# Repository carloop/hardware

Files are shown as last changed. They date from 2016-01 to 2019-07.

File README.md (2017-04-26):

<p align="center">
  Carloop Logo
</p>

# [Carloop](https://www.carloop.io)
## OBD-II CAN adapter for the Particle Photon/Electron and RedBear Duo

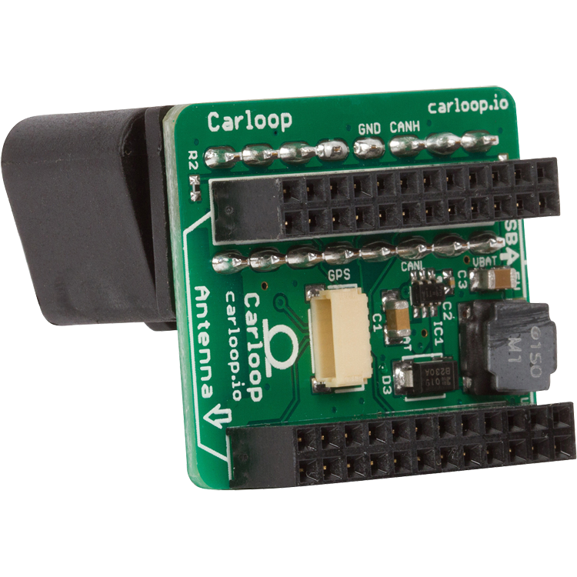
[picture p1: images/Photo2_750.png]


The WiFi-capable Particle Photon or better yet the cellular Particle
Electron can turn your car into a cloud connected device!

Carloop's PCB connects your car's CAN bus network to the Photon, Electron and Duo. It also provides battery power and a GPS to track location.

# Particle Photon Example

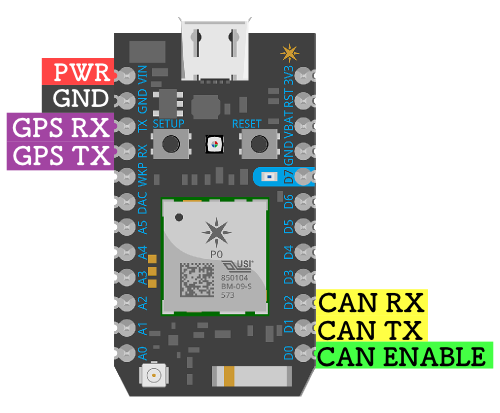
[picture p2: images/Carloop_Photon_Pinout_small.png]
Carloop Photon Pinout


# [Check out the Carloop Store](https://store.carloop.io/)

## Features

* High-speed CAN transceiver [adapted from the OpenXC project](https://github.com/openxc/reference-vi/blob/gh-pages/electrical/design/can.mkd)
* Get power from the OBD-II port using [a robust circuit adapted from the OpenXC project](https://github.com/openxc/reference-vi/blob/gh-pages/electrical/design/power.mkd)
* GPS connector
* Stacked components for a more compact development kit than a
traditional 90-degrees PCB mount OBD-II connector.
* Powered by the Particle platform!

## Images

PCB

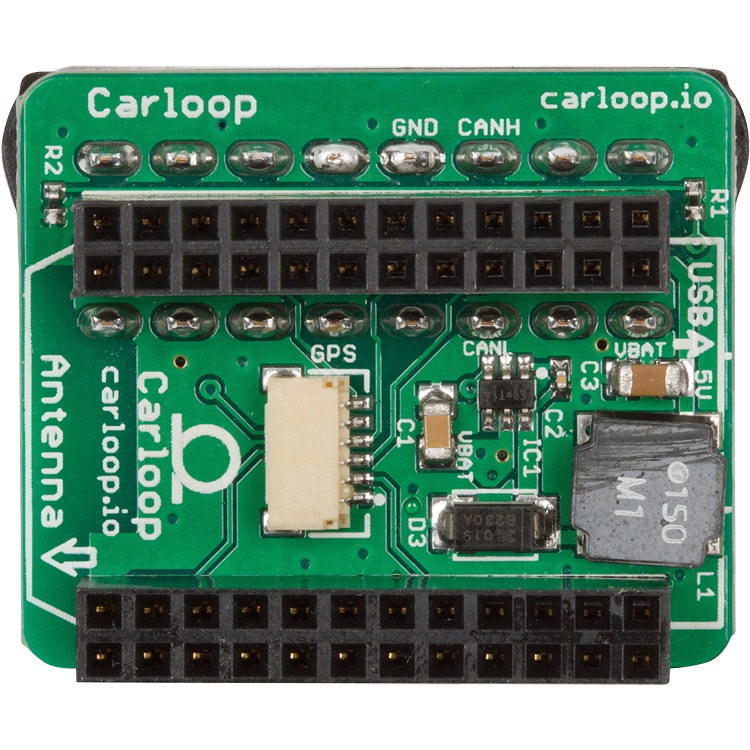
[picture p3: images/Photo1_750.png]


Assembled adapter

* [With Photon](images/detail-photon.jpg)
* [With Electron](images/detail-electron.jpg)
* [Front view](images/front.png)
* [Side view](images/detail-side.jpg)
* [Back view](images/back.png)
* [Angle view](images/angle.png)

## Hardware

There are a few hardware variants: [Carloop](Carloop.v2), [Carloop XL](CarloopXL.v3) and [Carloop Retro](CarloopRetro.v0).

Here are the PCB design files for the Revision 2.3, the one sold on the [Carloop store](https://store.carloop.io)

* [Schematic (PDF)](Carloop.v2/Carloop-v2.3.pdf)
  [(Eagle)](Carloop.v2/Carloop-v2.3.sch)
* [Layout](Carloop.v2/Carloop-v2.3-pcb-combined.pdf)
  [(top)](Carloop.v2/Carloop-v2.3-layout-top.pdf)
  [(bottom)](Carloop.v2/Carloop-v2.3-layout-bottom.pdf)
  [(Eagle)](Carloop.v2/Carloop-v2.3.brd)
* [Bill of materials](Carloop.v2/Carloop-v2.3_BOM.csv)
* [OSH Park order page](https://oshpark.com/shared_projects/ir8I9vT6)

Here are the PCB design files for the extended version that fits a Particle Electron. It is a prototype.

* [Schematic (Eagle)](CarloopXL.v3/Carloop-v3.1.sch)
* [Layout (Eagle)](CarloopXL.v3/Carloop-v3.1.brd)
* [Bill of materials](CarloopXL.v3/Carloop-v3.1_BOM.csv)

Here are the PCB design files for a "retro" variant with a K-Line transceiver contributed by [Alan R](https://github.com/cyclin-al).

* [Schematic (Eagle)](CarloopRetro.v0/CarloopRetro-v0.1.sch)
* [Layout (Eagle)](CarloopRetro.v0/CarloopRetro-v0.1.brd)

## Software

The [Carloop Library](https://github.com/carloop/carloop-library) is available on Particle's Web IDE.  You will need to flash a [Particle Photon](https://store.carloop.io/products/particle-photon), [Particle Electron](https://store.carloop.io/products/particle-electron) or [RedBear Duo](https://store.carloop.io/products/redbear-duo) with an example app which can ben found in Carloop Library.   See 'Getting Started' instructions here: [https://community.carloop.io/t/getting-started-with-carloop/23](https://community.carloop.io/t/getting-started-with-carloop/23)

## License

Copyright 2016 1000 Tools, Inc.

Licensed under the GPL v3

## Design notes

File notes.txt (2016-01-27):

Smaller CAN transceiver:
SN65HVD23x 3.3V 8 pin SOIC
http://www.ti.com/lit/ds/symlink/sn65hvd230.pdf

==> See layout guidelines

TJA1049 8 SOIC with 5V supply and 3.3V IO:
http://www.nxp.com/documents/data_sheet/TJA1049.pdf

Supply: LM2940-N IC REG LDO 5V 1A SOT223
==============> THIS HAS REVERSE BATTERY PROTECTION ELIMINATING 1 COMPONENT!!!!!!
Input cap: CAP CER 0.47UF 50V X7R 0805	C0805C474K5RACTU

Reverse protection diode:

SparkFun uses MBRA140 (1A, 0.56V drop, 40V reverse)

OpenXC uses RS1J (1A, 1.56V drop, 600V reverse)

  ==> Use MBRA140

0.016 width for power supply trace

Make VCC plane around regulator (both sides if possible) and use a bunch
of vias under the case to transfer heat.

MicroSD card => Just connecto to SPI (no external interfacing needed)

Amphenol http://www.digikey.com/product-detail/en/114-00841-68/114-00841-68-1-ND/2187101
Molex http://www.digikey.com/product-detail/en/1040310811/WM6357CT-ND/2804769

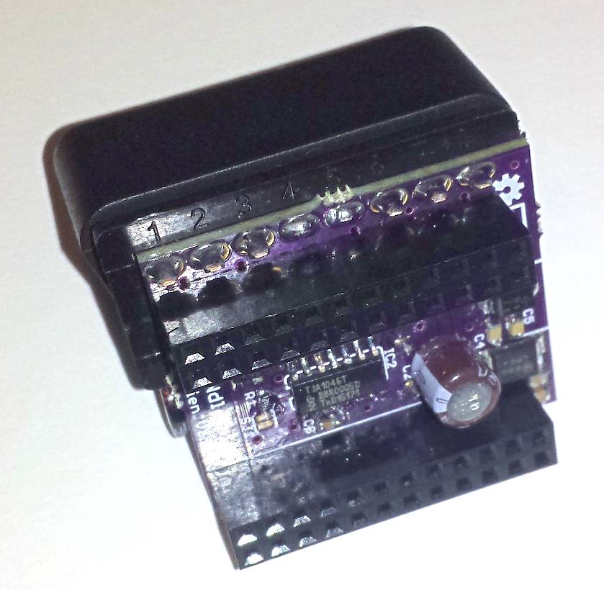
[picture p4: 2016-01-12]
images/detail-angle.jpg

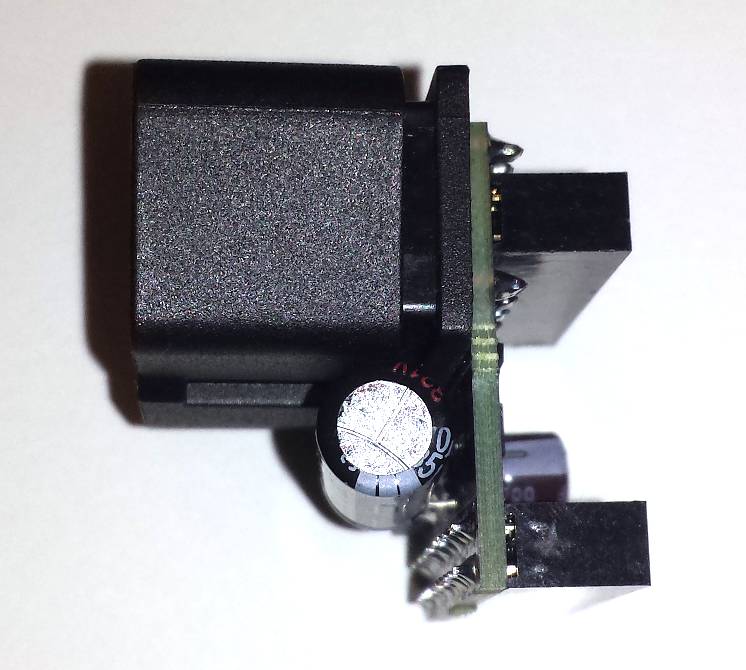
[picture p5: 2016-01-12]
images/detail-side.jpg

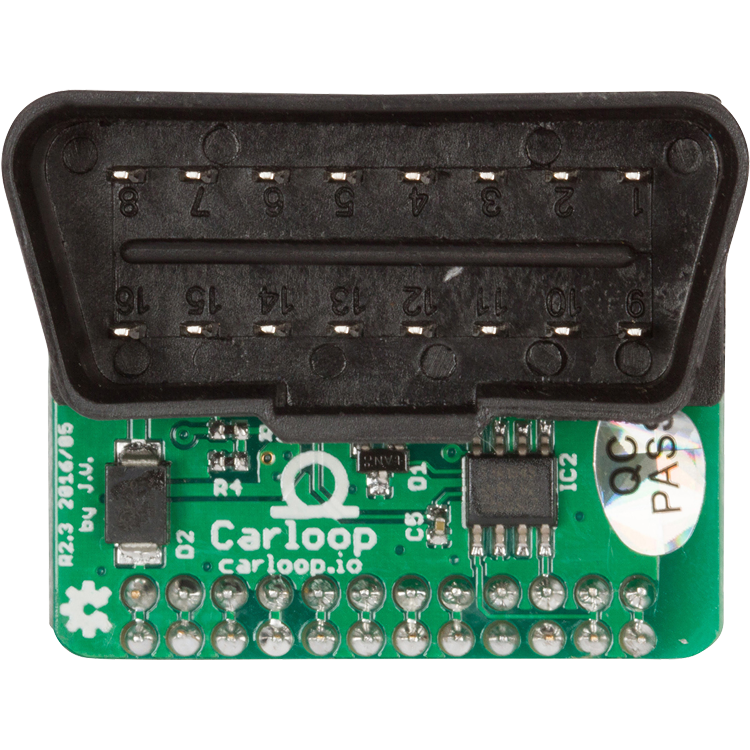
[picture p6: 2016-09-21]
images/back.png

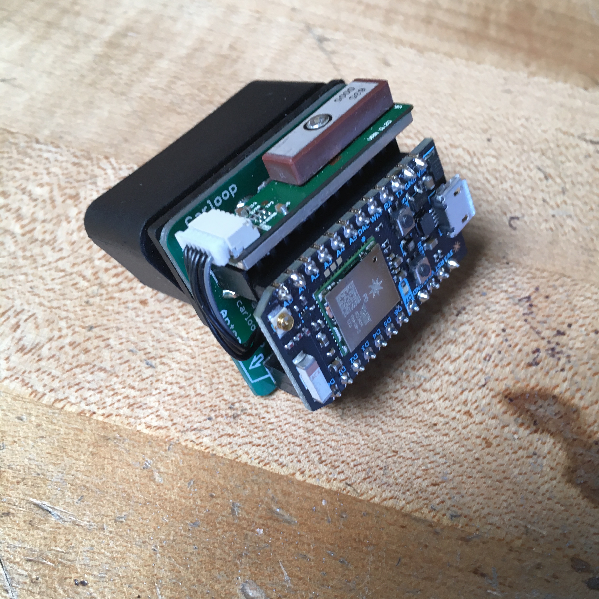
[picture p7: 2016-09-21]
images/detail-photon.jpg

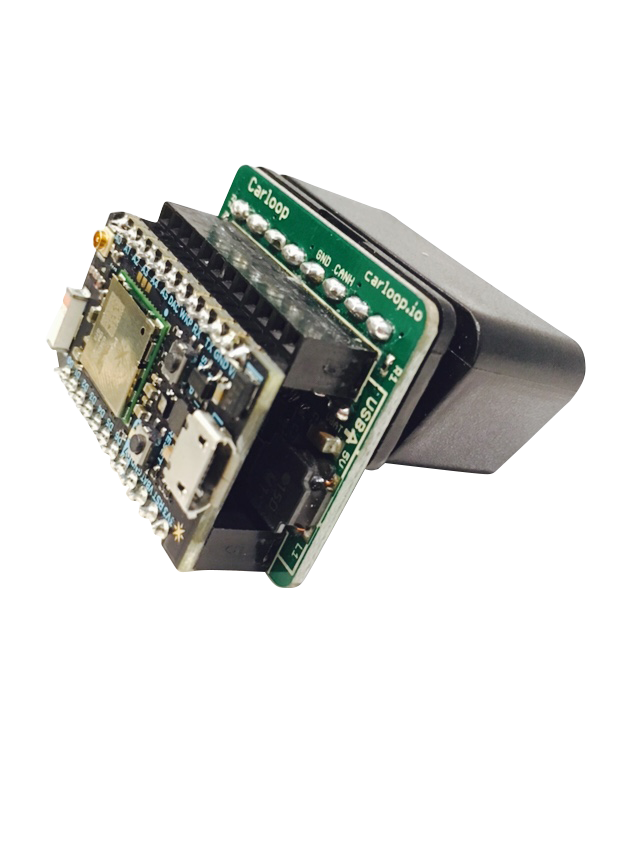
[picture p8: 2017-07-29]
images/Carloop Basic_Transparent_BG.png

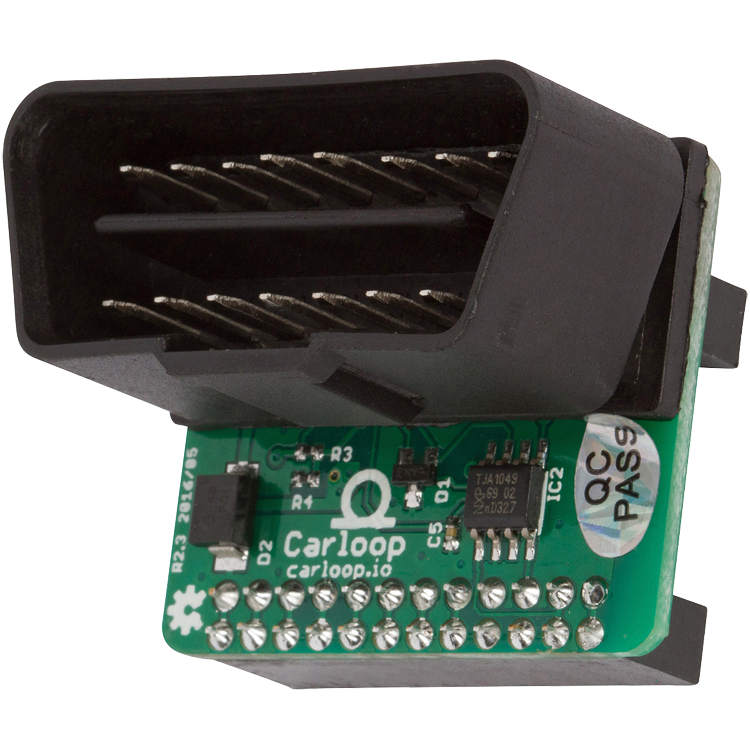
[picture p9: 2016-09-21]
images/angle.png

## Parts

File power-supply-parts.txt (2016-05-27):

Cin: 10uF GRM31CR61E106K
Cout: 22uF GRM31CR61C226M
D1: Schottky B230A-13-F
Cb: 10nF
R1: 91k
R2: 17.4k
L: 15uH NR8040T150M

Reverse protection:
--> 600V 2A silicon ultrafast reverse protection diode
Or Schottky like MBRA140 but for 2A

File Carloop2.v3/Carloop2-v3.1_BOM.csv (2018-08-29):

Qty-1 | Part References | Value | Package | Mfg Part Num | Mfg Name | VID | Vendor Part Num | Description | XREF
1 | J2 |  | SCREWTERMINAL-3.5MM-4 | OSTTE040104 | On Shore Technology Inc. | DK | ED2742-ND | TERMINAL BLOCK 3.5MM 4POS PCB | REF70
3 | C6, C7, C8 | 0.1uF | C0603 | CC0603JRX7R7BB104 | Yageo | DK | 311-1776-1-ND | CAP CER 0.1UF 16V X7R 0603 | REF12
1 | D2 | 1SMB16CAT3G | SMB-DIODE | 1SMB16CAT3G | ON Semiconductor | DK | 1SMB16CAT3GOSCT-ND | TVS DIODE 16VWM 26VC SMB | REF1
1 | R2 | 10k | R0603 | ERA-3AED103V | Panasonic Electronic Components | DK | P123734CT-ND | RES SMD 10K OHM 0.5% 1/10W 0603 | REF92
1 | C2 | 10nF | C0603 | CGA3E2X8R1H103K080AA | TDK Corporation | DK | 445-5892-1-ND | CAP CER 10000PF 50V X8R 0603 | REF88
3 | C1, C11, C12 | 10uF | C1206 | C3216X7R1E106K160AB | TDK Corporation | DK | 445-7705-1-ND | CAP CER 10UF 25V X7R 1206 | REF87
1 | L1 | 15uH | NR8040 | NR8040T150M | Taiyo-Yuden | DK | 587-2643-1-ND | FIXED IND 15UH 2.4A 65 MOHM SMD | REF46
1 | R4 | 17.4k | R0603 | ERJ-3EKF1742V | Panasonic Electronic Components | DK | P17.4KHCT-ND | RES SMD 17.4K OHM 1% 1/10W 0603 | REF93
2 | C4, C5 | 22pF | C0603 | CC0603KRX7R9BB223 | Yageo | DK | 311-1370-1-ND | CAP CER 0.022UF 50V X7R 0603 | REF13
1 | C3 | 22uF | C1206 | CL31X226KAHN3NE | Samsung Electro-Mechanics | DK | 1276-3299-1-ND | CAP CER 22UF 25V X6S 1206 | REF89
1 | Q1 | 40MHz | CRYSTAL-SMD-5X3 | ECS-400-12-30B-AGM-TR | ECS Inc. | DK | XC2600CT-ND | CRYSTAL 40MHZ 12PF SMD | REF84
1 | R1 | 62k | R0603 | ERA-3AEB623V | Panasonic Electronic Components | DK | P62KDBCT-ND | RES SMD 62K OHM 0.1% 1/10W 0603 | REF90
1 | R3 | 91k | R0603 | ERA-3ARB913V | Panasonic Electronic Components | DK | P91KBDCT-ND | RES SMD 91K OHM 0.1% 1/10W 0603 | REF91
1 | IC2 | AZ1117E | SOT223 | AZ1117EH-3.3TRG1 | Diodes Incorporated | DK | AZ1117EH-3.3TRG1DICT-ND | IC REG LINEAR 3.3V 1A SOT223 | REF81
1 | D3 | B230A | DO-214AA | B230A-13-F | Diodes-Incorporated | DK | B230A-FDICT-ND | DIODE SCHOTTKY 30V 2A SMA | REF43
1 | HEADER24 | BOM-PART | * | NPPC122KFMS-RC | Sullins Connector Solutions | DK | S5721-ND | CONN FMALE 24POS DL .1"" GOLD SMD | REF85
1 | HEADER30 | BOM-PART | * | NPTC152KFMS-RC | Sullins Connector Solutions | DK | S5685-ND | CONN FEMALE 30POS DL .1"" TIN SMD | REF86
2 | D4, D5 | MBRA140 | SMA-DIODE | MBRA140T3G | ON Semiconductor | DK | MBRA140T3GOSCT-ND | DIODE SCHOTTKY 40V 1A SMA | REF80
1 | IC4 | MCP2517FD | SOIC-14 | MCP2517FD-H/SL | Microchip Technology | DK | MCP2517FD-H/SL-ND | STAND-ALONE CAN FD CONTROLLER W/ | REF82
1 | J1 | OBDII | OBDII-COMTECH | OBD-II | COMTECH | SF | DEV-09911 | OBD-II connector Straight | REF6
1 | D1 | PESD1CAN | SOT23 | PESD1CAN-215 | NXP Semiconductors | DK | 568-4032-1-ND | TVS DIODE 24VWM 70VC SOT23 | REF2
1 | IC1 | RT8258 | SOT-23-6 | RT8258GJ6 | Richtek | DK | 1028-1044-1-ND | IC REG BUCK ADJ 1.2A TSOT23-6 | REF47
1 | IC3 | TJA1049 | SO8 | TJA1049T-118 | NXP Semiconductors | DK | 568-8682-1-ND | IC CAN TRANSEIVER HS 8SOIC | REF16

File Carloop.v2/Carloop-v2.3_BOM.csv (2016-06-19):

Qty-1 | Part References | Value | Package | Mfg Part Num | Mfg Name | VID | Vendor Part Num | Description | XREF
1 | C5 | 0.1u | C0402 | GRM155R71C104KA88D | Murata | DK | 490-3261-1-ND | 0.10µF ±10% 16V X7R Ceramic Capacitor -55°C ~ 125°C Surface Mount MLCC 0402 | REF48
1 | D2 | 1SMB16CAT3G | SMB-DIODE | 1SMB16CAT3G | ON Semiconductor | DK | 1SMB16CAT3GOSCT-ND | TVS DIODE 16VWM 26VC SMB | REF1
1 | R2 | 10k | R0402 | ERJ-2RKF1002X | Panasonic Electronic Components | DK | P10.0KLCT-ND | RES SMD 10K OHM 1% 1/10W 0402 | REF50
1 | C2 | 10n | C0402 | C0402C103K5RACTU | Kemet | DK | 399-3066-1-ND | 10000pF ±10% 50V X7R Ceramic Capacitor -55°C ~ 125°C Surface Mount MLCC 0402 | REF42
1 | C1 | 10uF | C1206 | GRM31CR61E106KA12L | Murata | DK | 490-3373-1-ND | 10µF ±10% 25V X5R Ceramic Capacitor -55°C ~ 85°C Surface Mount MLCC 1206 | REF40
1 | L1 | 15uH | NR8040 | NR8040T150M | Taiyo-Yuden | DK | 587-2643-1-ND | FIXED IND 15UH 2.4A 65 MOHM SMD | REF46
1 | R4 | 17.4k | R0402 | ERJ-2RKF1742X | Panasonic Electronic Components | DK | P17.4KLCT-ND | RES SMD 17.4K OHM 1% 1/10W 0402 | REF45
1 | C3 | 22u | C1206 | GRM31CR61C226ME15L | Murata | DK | 490-4739-1-ND | 22µF ±20% 16V X5R Ceramic Capacitor -55°C ~ 85°C Surface Mount MLCC 1206 | REF41
1 | R1 | 62k | R0402 | ERJ-2RKF6202X | Panasonic Electronic Components | DK | P62.0KLCT-ND | RES SMD 62K OHM 1% 1/10W 0402 | REF49
1 | R3 | 91k | R0402 | ERJ-2RKF9102X | Panasonic Electronic Components | DK | P91.0KLCT-ND | RES SMD 91K OHM 1% 1/10W 0402 | REF44
1 | D3 | B230A | DO-214AA | B230A-13-F | Diodes-Incorporated | DK | B230A-FDICT-ND | DIODE SCHOTTKY 30V 2A SMA | REF43
2 | HEADER1, HEADER2 | BOM-ENTRY | * | PPPC122LFBN-RC | Sullins Connector Solutions | DK | S7115-ND | Connector Header 24 Position 0.100in (2.54mm) Gold Through Hole | REF8
1 | GPS | JSTHORIZONTAL | JST-6-SMD-HOR-1.0MM | SM06B-SRSS-TB | JST | DK | 455-1806-1-ND | CONN HEADER SH 6POS SIDE 1MM TIN | REF39
1 | J1 | OBDII | OBDII-STRAIGHT | OBD-II | COMTECH | SF | DEV-09911 | OBD-II connector Straight | REF6
1 | D1 | PESD1CAN | SOT23 | PESD1CAN-215 | NXP Semiconductors | DK | 568-4032-1-ND | TVS DIODE 24VWM 70VC SOT23 | REF2
1 | IC1 | RT8258 | SOT-23-6 | RT8258GJ6 | Richtek | DK | 1028-1044-1-ND | IC REG BUCK ADJ 1.2A TSOT23-6 | REF47
1 | IC2 | TJA1049 | SO8 | TJA1049T-118 | NXP Semiconductors | DK | 568-8682-1-ND | IC CAN TRANSEIVER HS 8SOIC | REF16

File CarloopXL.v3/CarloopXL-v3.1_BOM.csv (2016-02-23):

Qty-1 | Part References | Value | Package | Mfg Part Num | Mfg Name | VID | Vendor Part Num | Description | XREF
1 | C1 | .47u | C0805 | C0805C474K5RACTU | Kemet | DK | 399-8100-1-ND | CAP CER 0.47UF 50V X7R 0805 | REF19
2 | C5, C6 | 0.1u | C0805 | 08055C104KAT2A | AVX | DK | 478-1395-1-ND | CAP CER 0.1UF 50V X7R 0805 | REF20
1 | D2 | 1SMB16CAT3G | SMB-DIODE | 1SMB16CAT3G | ON Semiconductor | DK | 1SMB16CAT3GOSCT-ND | TVS DIODE 16VWM 26VC SMB | REF1
1 | C7 | 1u | C0805 | CC0805KKX7R7BB105 | Yageo | DK | 311-1365-1-ND | CAP CER 1UF 16V X7R 0805 | REF26
1 | R2 | 10k | R0805 | ERJ-6ENF1002V | Panasonic Electronic Components | DK | P10.0KCCT-ND | RES SMD 10K OHM 1% 1/8W 0805 | REF38
1 | C2 | 10u | C0805 | GRM21BR6YA106KE43L | Murata | DK | 490-10514-1-ND | CAP CER 10UF 35V X5R 0805 | REF27
1 | C3 | 22u | C0805 | GRM219R61A226MEA0D | Murata | DK | 490-9951-1-ND | CAP CER 22UF 10V X5R 0805 | REF21
1 | R1 | 62k | R0805 | ERJ-6ENF6202V | Panasonic Electronic Components | DK | P62.0KCCT-ND | RES SMD 62K OHM 1% 1/8W 0805 | REF37
1 | D4 | BAT54S | SOT23 | BAT54S-7-F | Diodes Incorporated | DK | BAT54S-FDICT-ND | DIODE ARRAY SCHOTTKY 30V SOT23-3 | REF36
1 | C4 | DNP | C0805 | GRM219R61A226MEA0D | Murata | DK | 490-9951-1-ND | CAP CER 22UF 10V X5R 0805 | REF21
1 | ELECTRON | ELECTRON_WITH_EXTERNAL_HEADERS | ELECTRON_EXTERNAL | PPTC181LFBN-RC | Sullins Connector Solutions | DK | S7016-ND | CONN HEADER FEMALE 18POS.1"" TIN | REF23
1 | GPS | JST | JST-6-SMD-VERT-1.0MM | BM06B-SRSS-TB | JST | DK | 455-1792-1-ND | CONN HEADER SH 6POS TOP 1MM TIN | REF25
1 | IC1 | NCP1117CORRECT | SOT223 | NCP1117LPST50T3G | ON Semiconductor | DK | NCP1117LPST50T3GOSCT-ND | IC REG LDO 5V 1A SOT223 | REF28
1 | J1 | OBDII | OBDII-COMTECH | OBD-II | COMTECH | SF | DEV-09911 | OBD-II connector Straight | REF6
1 | D1 | PESD1CAN | SOT23 | PESD1CAN-215 | NXP Semiconductors | DK | 568-4032-1-ND | TVS DIODE 24VWM 70VC SOT23 | REF2
1 | D3 | RS1J | SMA-DIODE | RS1J-E3/5AT | Vishay | DK | RS1J-E3/5ATGICT-ND | DIODE GEN PURP 600V 1A DO214AC | REF3
1 | IC2 | TJA1049 | SO8 | TJA1049T-118 | NXP Semiconductors | DK | 568-8682-1-ND | IC CAN TRANSEIVER HS 8SOIC | REF16
1 | SDCARD | USD-SOCKETMOLEX-CORRECT | MICRO-SD-MOLEX-CORRECT | 1040310811 | Molex | DK | WM6357CT-ND | CONN MICRO SD CARD PUSH-PULL R/A | REF24

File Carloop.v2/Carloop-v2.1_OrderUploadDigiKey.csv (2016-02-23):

Digi-Key Part No. | Manufacturer Name | Mfr Part No. | Customer Reference | Qty1
1SMB16CAT3GOSCT-ND | ON Semiconductor | 1SMB16CAT3G | D3 | 12
478-1395-1-ND | AVX | 08055C104KAT2A | C5 | 12
399-8100-1-ND | Kemet | C0805C474K5RACTU | C1 | 12
P10.0KCCT-ND | Panasonic Electronic Components | ERJ-6ENF1002V | R2 | 12
P62.0KCCT-ND | Panasonic Electronic Components | ERJ-6ENF6202V | R1 | 12
490-9951-1-ND | Murata | GRM219R61A226MEA0D | C3 | 12
LM2940IMP-5.0/NOPBCT-ND | Texas Instruments | LM2940IMP-5.0/NOPB | IC1 | 12
568-4032-1-ND | NXP Semiconductors | PESD1CAN-215 | D1 | 12
S7115-ND | Sullins Connector Solutions | PPPC122LFBN-RC | CORE | 12
455-1806-1-ND | JST | SM06B-SRSS-TB | GPS | 12
568-8682-1-ND | NXP Semiconductors | TJA1049T-118 | IC2 | 12

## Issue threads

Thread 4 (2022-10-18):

Carloop as extension to Flipper Zero

amra, 2022-10-18:
[Flipper Zero](https://flipperzero.one/) is a hacking device released this year. It supports 3rd-party modules.

Adapt Carloop hardware, so it can be adapted as Flipper Zero module.

### Example: WiFi module
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

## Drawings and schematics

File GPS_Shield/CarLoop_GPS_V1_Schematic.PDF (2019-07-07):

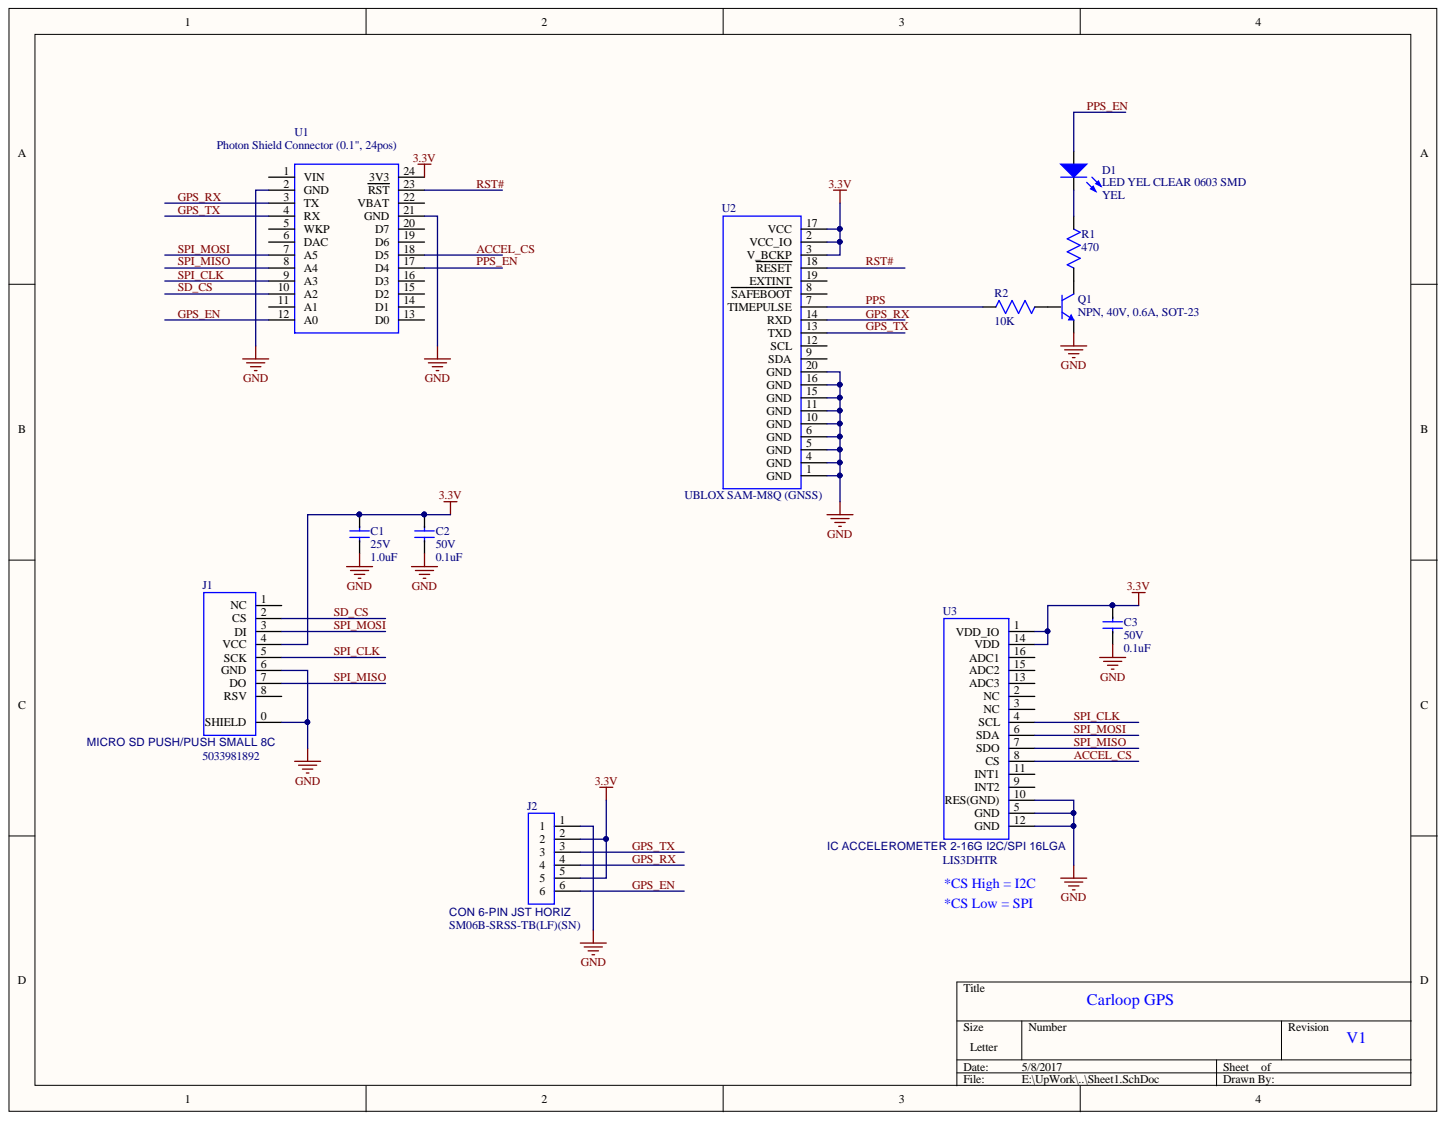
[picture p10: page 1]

MICRO SD PUSH/PUSH S

PIN JST HORIZ
6B-SRSS-TB(LF)(SN

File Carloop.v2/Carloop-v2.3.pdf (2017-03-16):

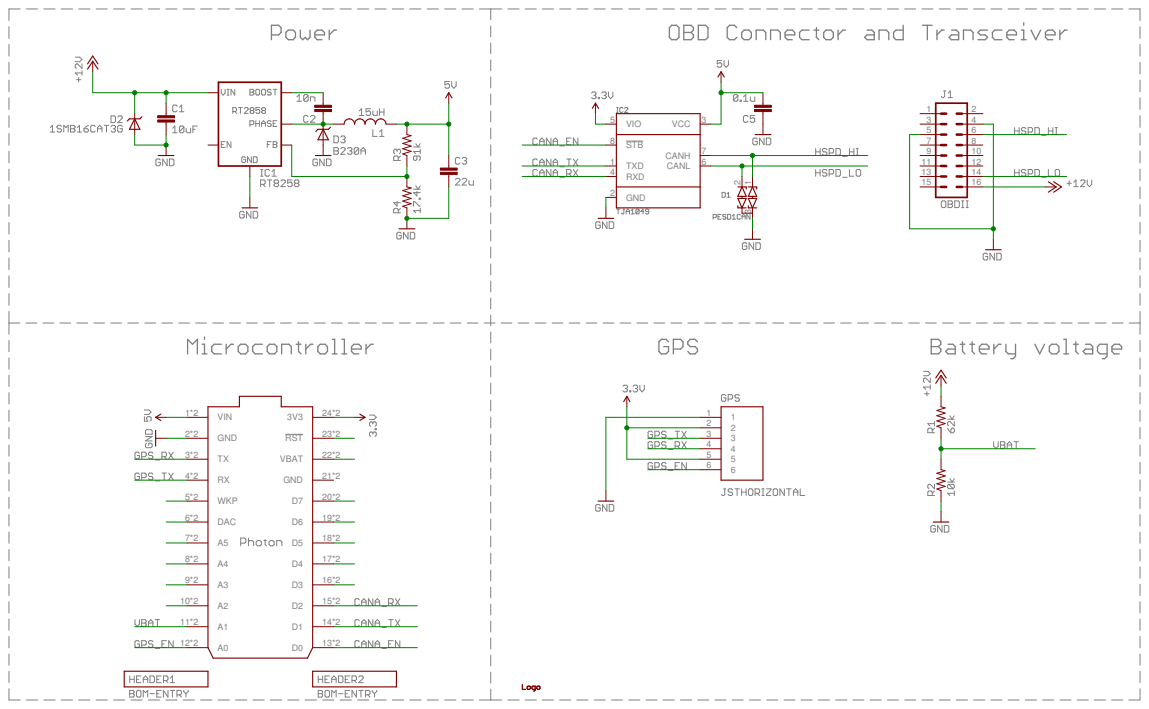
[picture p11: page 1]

21 3 1 2 3 4 5 6 7 8 9 10 11 12 13 14 15 16 VIN 1*2 GND 2*2 TX 3*2 RX 4*2 WKP 5*2 DAC 6*2 A5 7*2 A4 8*2 A3 9*2 A2 10*2 A1 11*2 A0 12*2 3V3 24*2 RST 23*2 VBAT 22*2 GND 21*2 D7 20*2 D6 19*2 D5 18*2 D4 17*2 D3 16*2 D2 15*2 D1 14*2 D0 13*2 STB 8 CANH 7 CANL 6 GND 2 RXD 4 TXD 1 VCC 3 VIO 5 1 1 2 2 3 3 4 4 5 5 6 6

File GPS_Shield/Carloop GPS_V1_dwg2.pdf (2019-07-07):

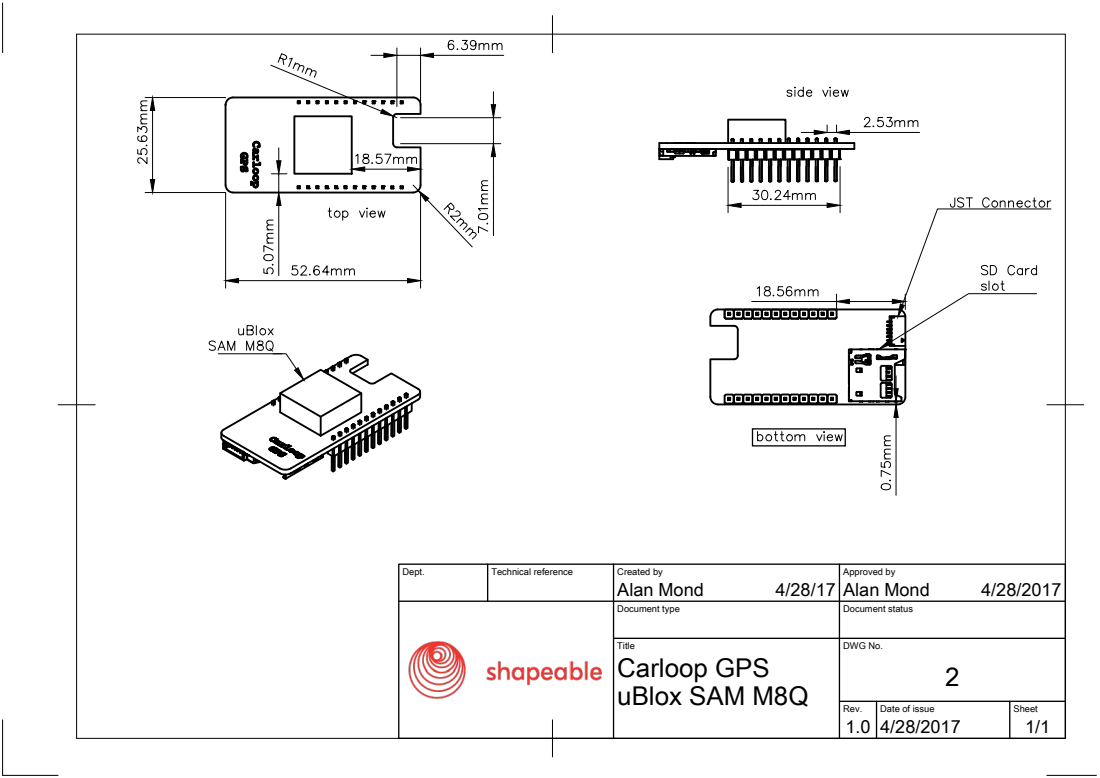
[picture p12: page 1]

Dept. | Technical reference | Created by Alan Mond 4/28/17 | Approved by Alan Mond 4/28/2017

Document type | Document status

Title Carloop GPS uBlox SAM M8Q | DWG No. 2

Rev. 1.0 | Date of issue 4/28/2017 | Sheet 1/1

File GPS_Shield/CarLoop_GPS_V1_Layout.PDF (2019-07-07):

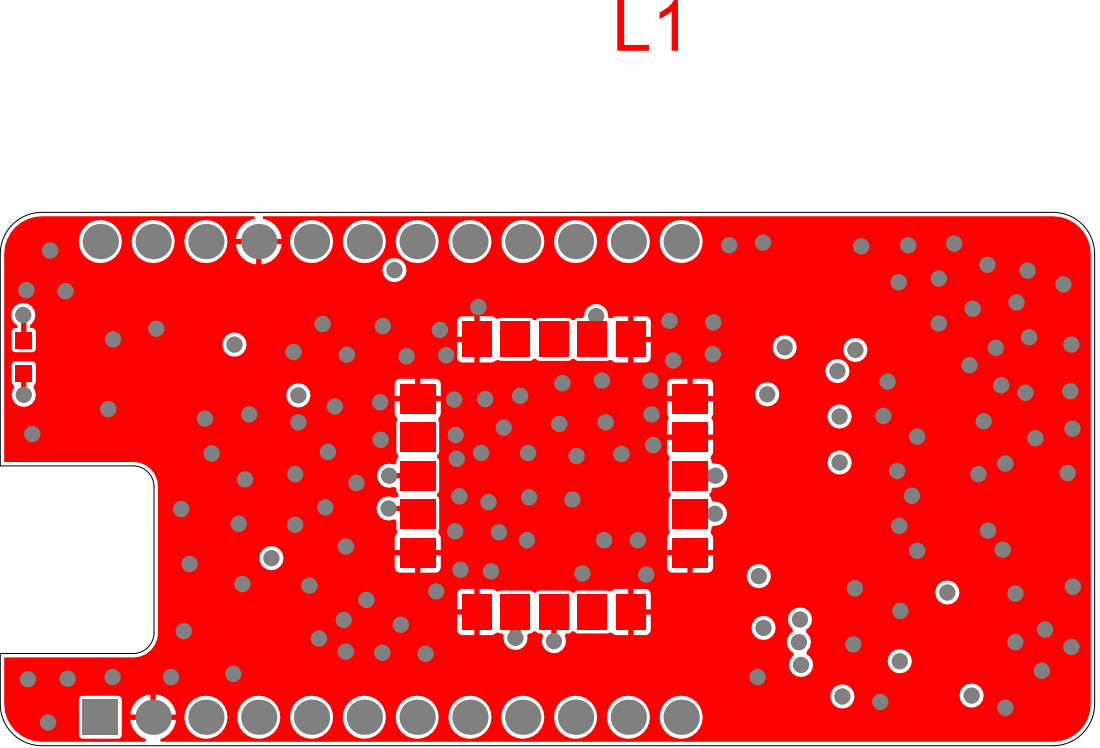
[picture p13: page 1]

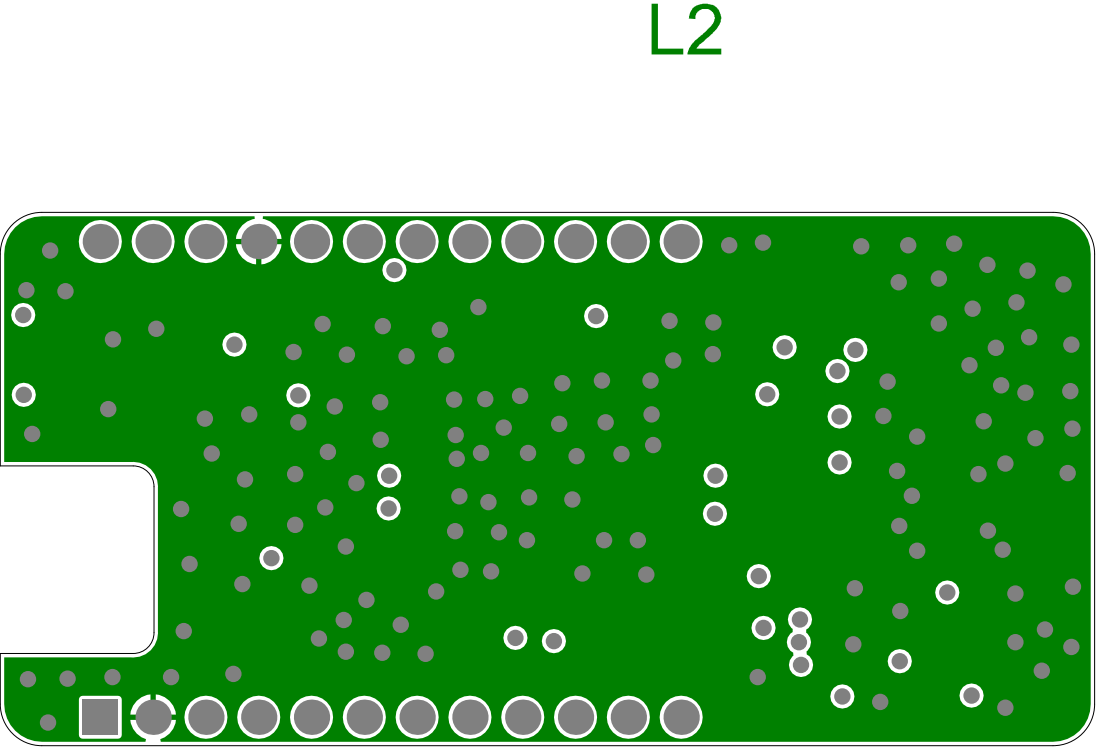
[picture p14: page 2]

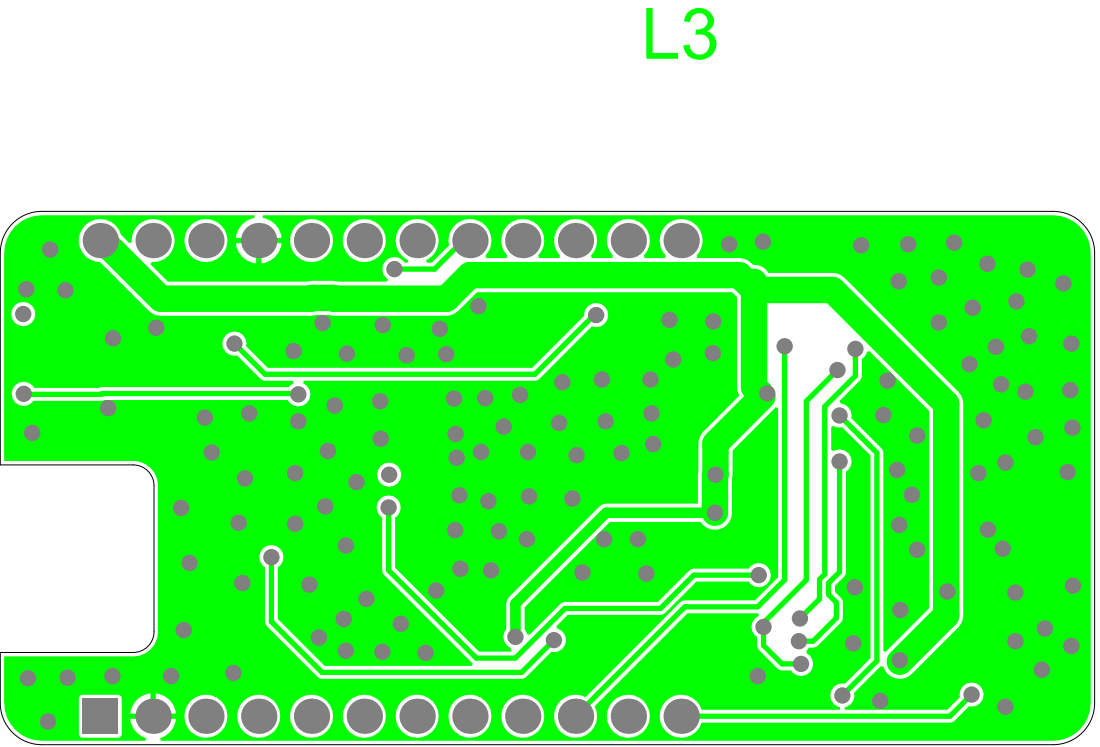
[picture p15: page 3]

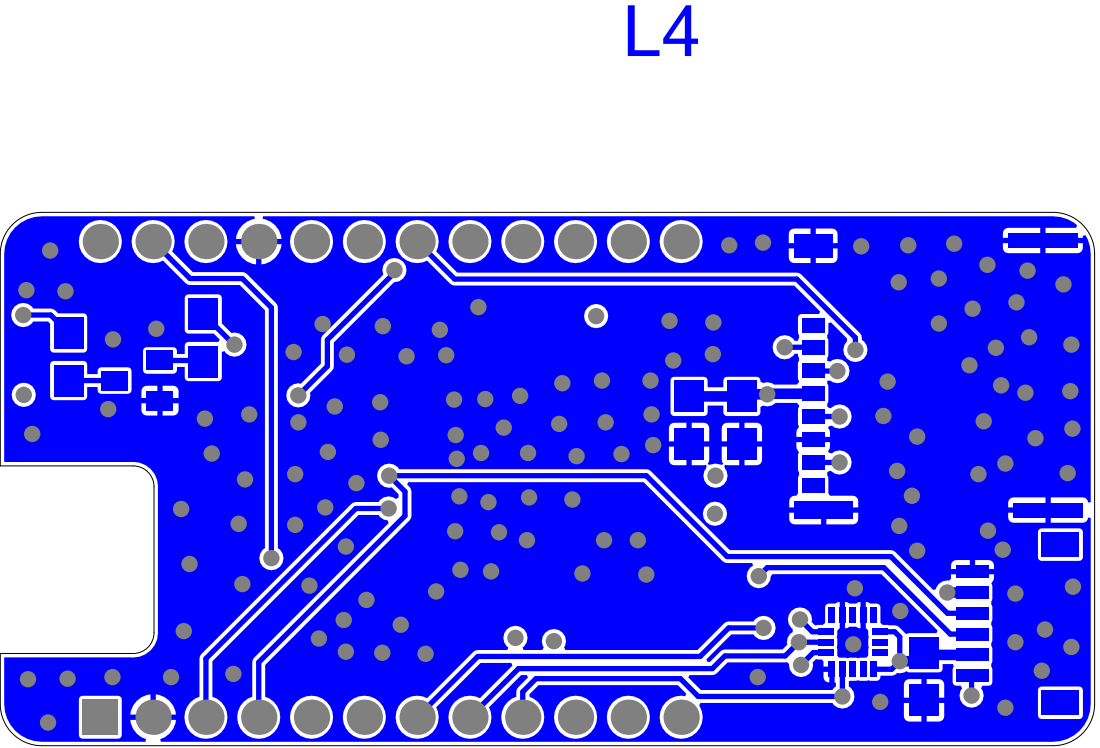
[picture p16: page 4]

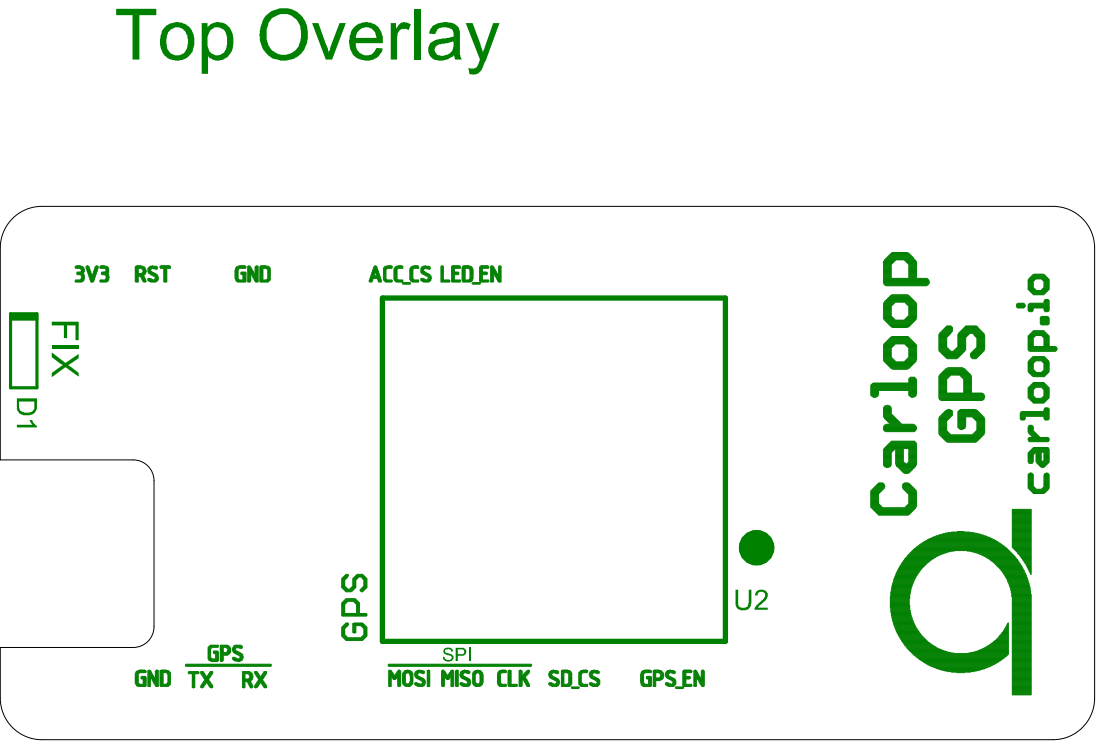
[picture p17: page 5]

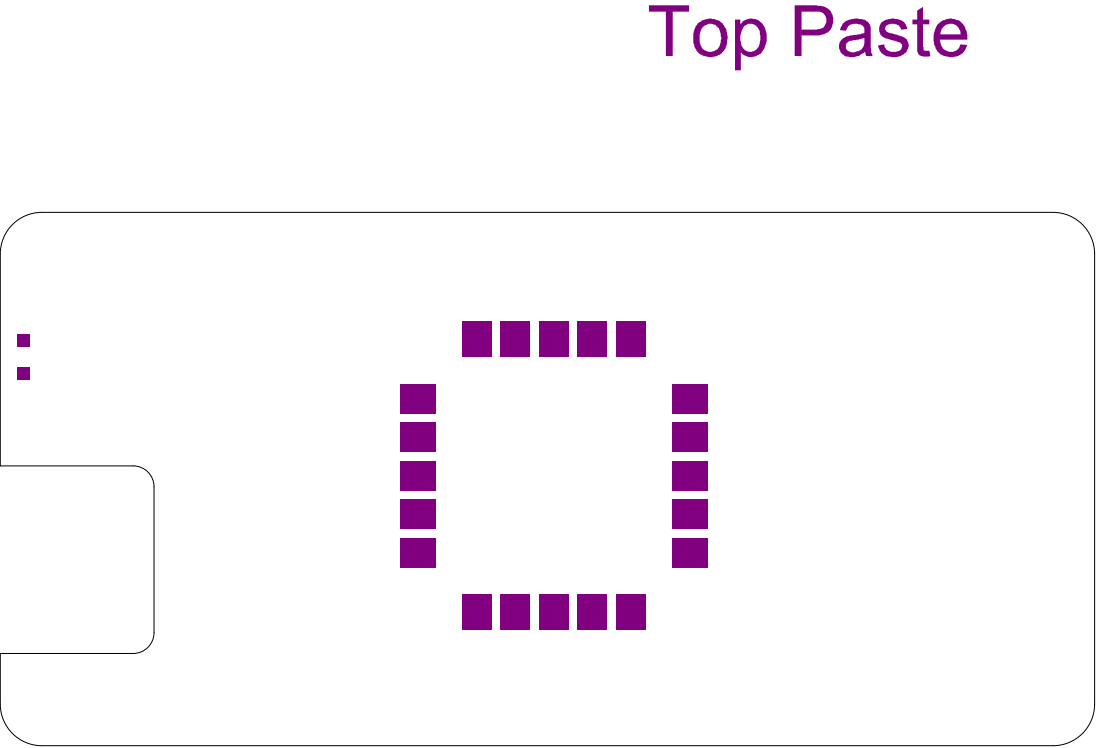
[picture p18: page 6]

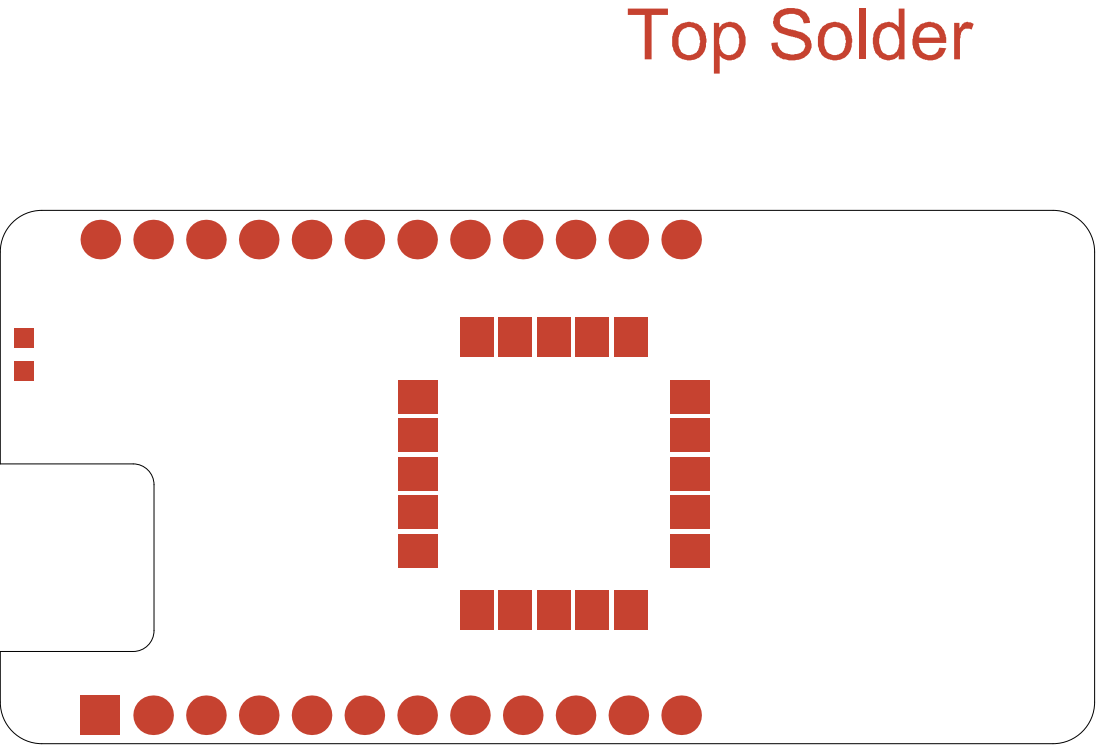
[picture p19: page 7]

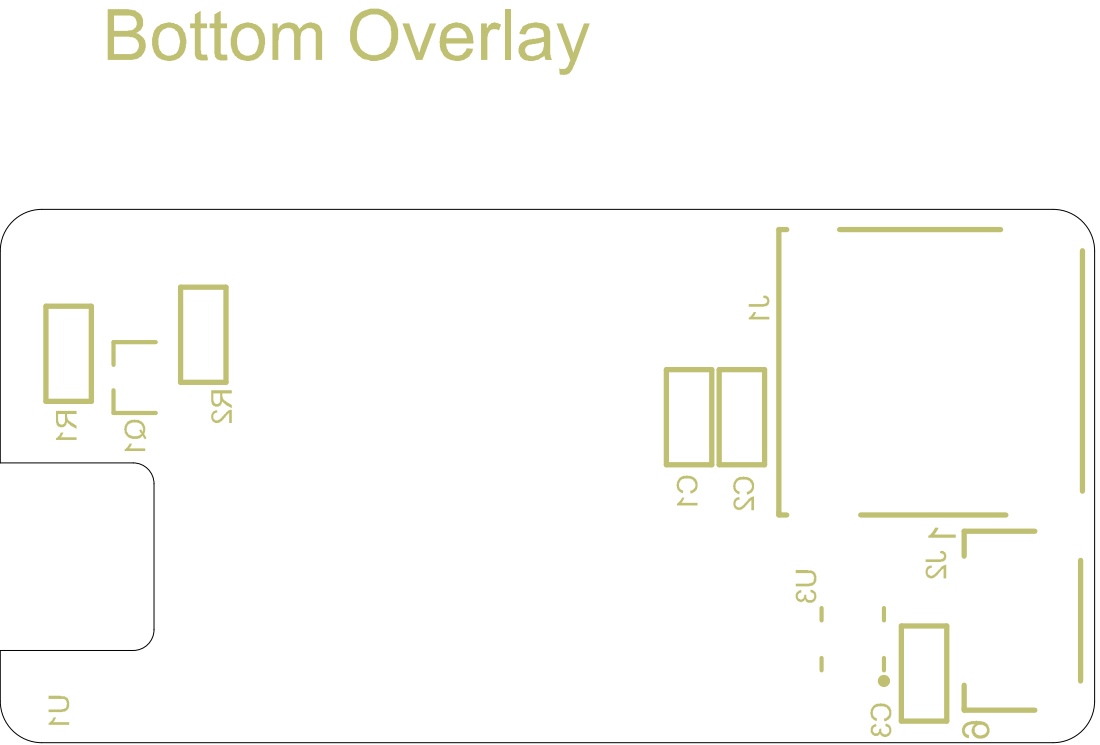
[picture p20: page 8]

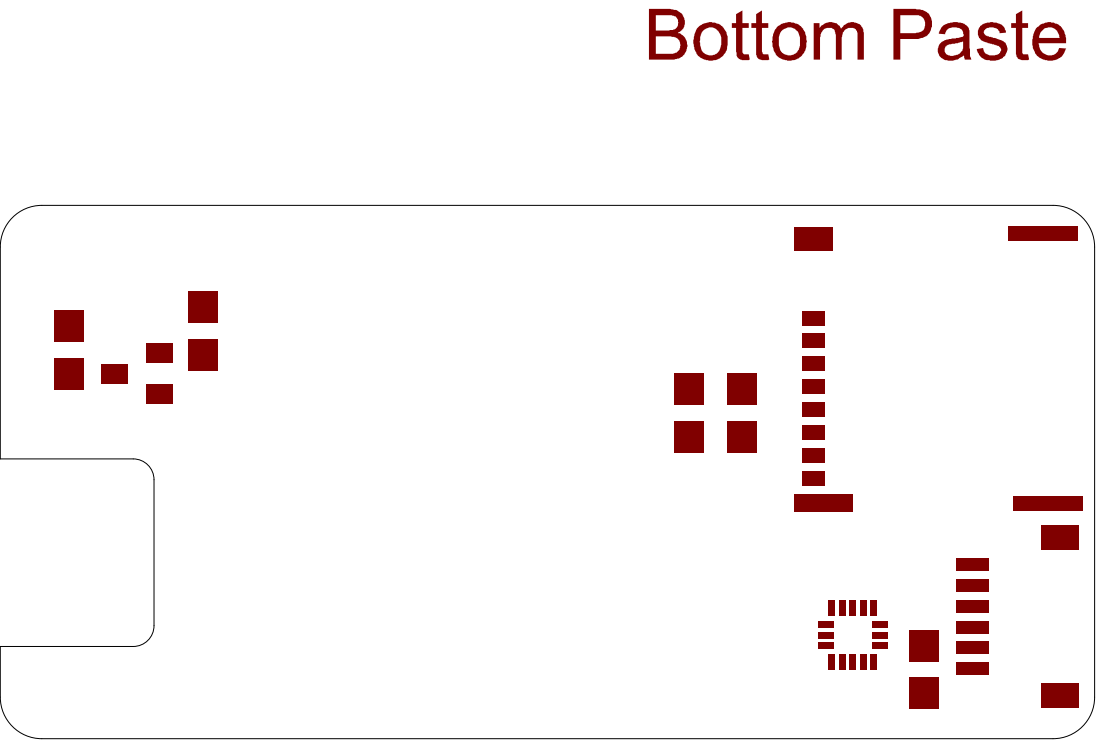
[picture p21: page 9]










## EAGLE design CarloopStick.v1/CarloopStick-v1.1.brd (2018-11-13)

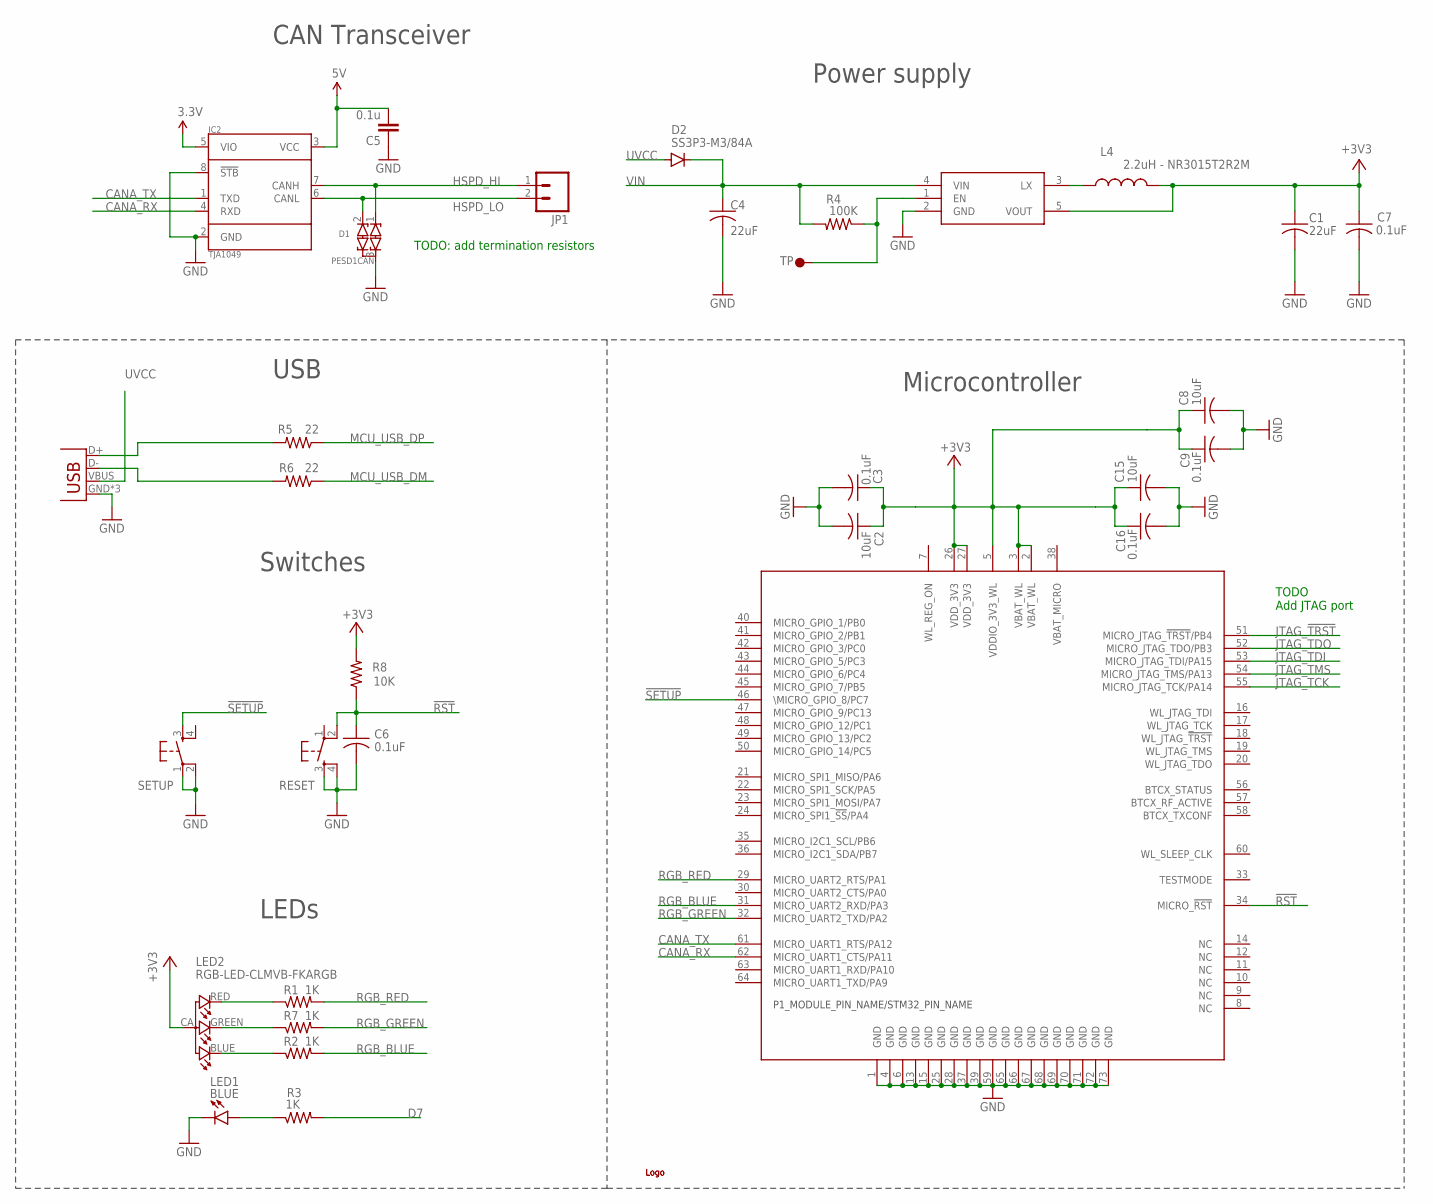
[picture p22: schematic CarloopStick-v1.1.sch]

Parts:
C1, C4: 22uF; C0603_B
C2, C8, C15: 10uF; C0603_B
C3, C6, C7, C9, C16: 0.1uF; C0402_B
C5: 0.1u; C0402; PARTNO GRM155R71C104KA88D
D1: PESD1CAN; SOT23; PARTNO PESD1CAN-215
D2: SS3P3-M3/84A; DIODE-DO-220AA(SMP)
IC2: TJA1049; SO8; PARTNO TJA1049T-118
JP1: M02PTH; 1X02
L4: 2.2uH - NR3015T2R2M; INDUCTOR-NR3015
LED2: RGB-LED-CLMVB-FKARGB; PLCC4-2MM-RGB
LED_USR: BLUE; LED-0603-NO-SS
R1, R2, R3, R7: 1K; R0402_B
R4: 100K; R0402_B
R5, R6: 22; R0402_B
R8: 10K; R0402_B
RESET: KMR211GLFS; TACTILE_SWITCH_SMD
SETUP: KMR211GLFS; TACTILE_SWITCH_SMD
U$1, U$5: LOGOSMALL; CARLOOP-2
U$4: P1; WM-N-BM-14
U$11: R8008-33; SOT23-5
U$12: TP3; TP60_BOT
X1: USB-MICROB; USB-MICROB-SLOT-HOLE

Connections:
3.3V: IC2.5 (VIO)
5V: C5.2, IC2.3 (VCC)
!RST: C6.1, R8.1, RESET.2, U$4.34 (MICRO_!RST!)
!SETUP: SETUP.3, U$4.46 (\MICRO_GPIO_8/PC7)
+3V3: C1.1, C2.1, C3.1, C7.1, C8.1, C9.1, C15.1, C16.1, L4.2, LED2.CA (1), R8.2, U$4.2 (VBAT_WL), U$4.3 (VBAT_WL), U$4.5 (VDDIO_3V3_WL), U$4.26 (VDD_3V3), U$4.27 (VDD_3V3), U$11.5 (VOUT)
CANA_RX: IC2.4 (RXD), U$4.62 (MICRO_UART1_CTS/PA11)
CANA_TX: IC2.1 (TXD), U$4.61 (MICRO_UART1_RTS/PA12)
D7: R3.2
GND: C1.2, C2.2, C3.2, C4.2, C5.1, C6.2, C7.2, C8.2, C9.2, C15.2, C16.2, D1.3 (COM), IC2.2 (GND), IC2.8 (!STB), LED_USR.C1 (C), RESET.3, RESET.4, SETUP.1, SETUP.2, U$4.1 (GND), U$4.4 (GND), U$4.6 (GND), U$4.13 (GND), U$4.15 (GND), U$4.25 (GND), U$4.28 (GND), U$4.37 (GND), U$4.39 (GND), U$4.59 (GND), U$4.65 (GND), U$4.66 (GND), U$4.67 (GND), U$4.68 (GND), U$4.69 (GND), U$4.70 (GND), U$4.71 (GND), U$4.72 (GND), U$4.73 (GND), U$11.2 (GND), X1.GND, X1.MT1 (GND), X1.MT2 (GND)
HSPD_HI: D1.1 (C1), IC2.7 (CANH), JP1.1
HSPD_LO: D1.2 (C2), IC2.6 (CANL), JP1.2
JTAG_!TRST: U$4.51 (MICRO_JTAG_!TRST!/PB4)
JTAG_TCK: U$4.55 (MICRO_JTAG_TCK/PA14)
JTAG_TDI: U$4.53 (MICRO_JTAG_TDI/PA15)
JTAG_TDO: U$4.52 (MICRO_JTAG_TDO/PB3)
JTAG_TMS: U$4.54 (MICRO_JTAG_TMS/PA13)
LED1: LED_USR.A1 (A), R3.1
MCU_USB_DM: R6.1
MCU_USB_DP: R5.1
unnamed: R5.2, X1.D+
unnamed: L4.1, U$11.3 (LX)
unnamed: R6.2, X1.D-
unnamed: R4.1, U$11.1 (EN), U$12.P$1
unnamed: LED2.BLUE (2), R2.1
unnamed: LED2.GREEN (3), R7.1
unnamed: LED2.RED (4), R1.1
RGB_BLUE: R2.2, U$4.31 (MICRO_UART2_RXD/PA3)
RGB_GREEN: R7.2, U$4.32 (MICRO_UART2_TXD/PA2)
RGB_RED: R1.2, U$4.29 (MICRO_UART2_RTS/PA1)
UVCC: D2.ANODE, X1.VBUS
VIN: C4.1, D2.CATHODE, R4.2, U$11.4 (VIN)

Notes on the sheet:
CAN Transceiver
USB
Microcontroller
Power supply
Switches
LEDs
TODO Add JTAG port
TODO: add termination resistors

Board: 2 copper layers, 34 parts (0 on the bottom side), 22 nets, no tracks yet.

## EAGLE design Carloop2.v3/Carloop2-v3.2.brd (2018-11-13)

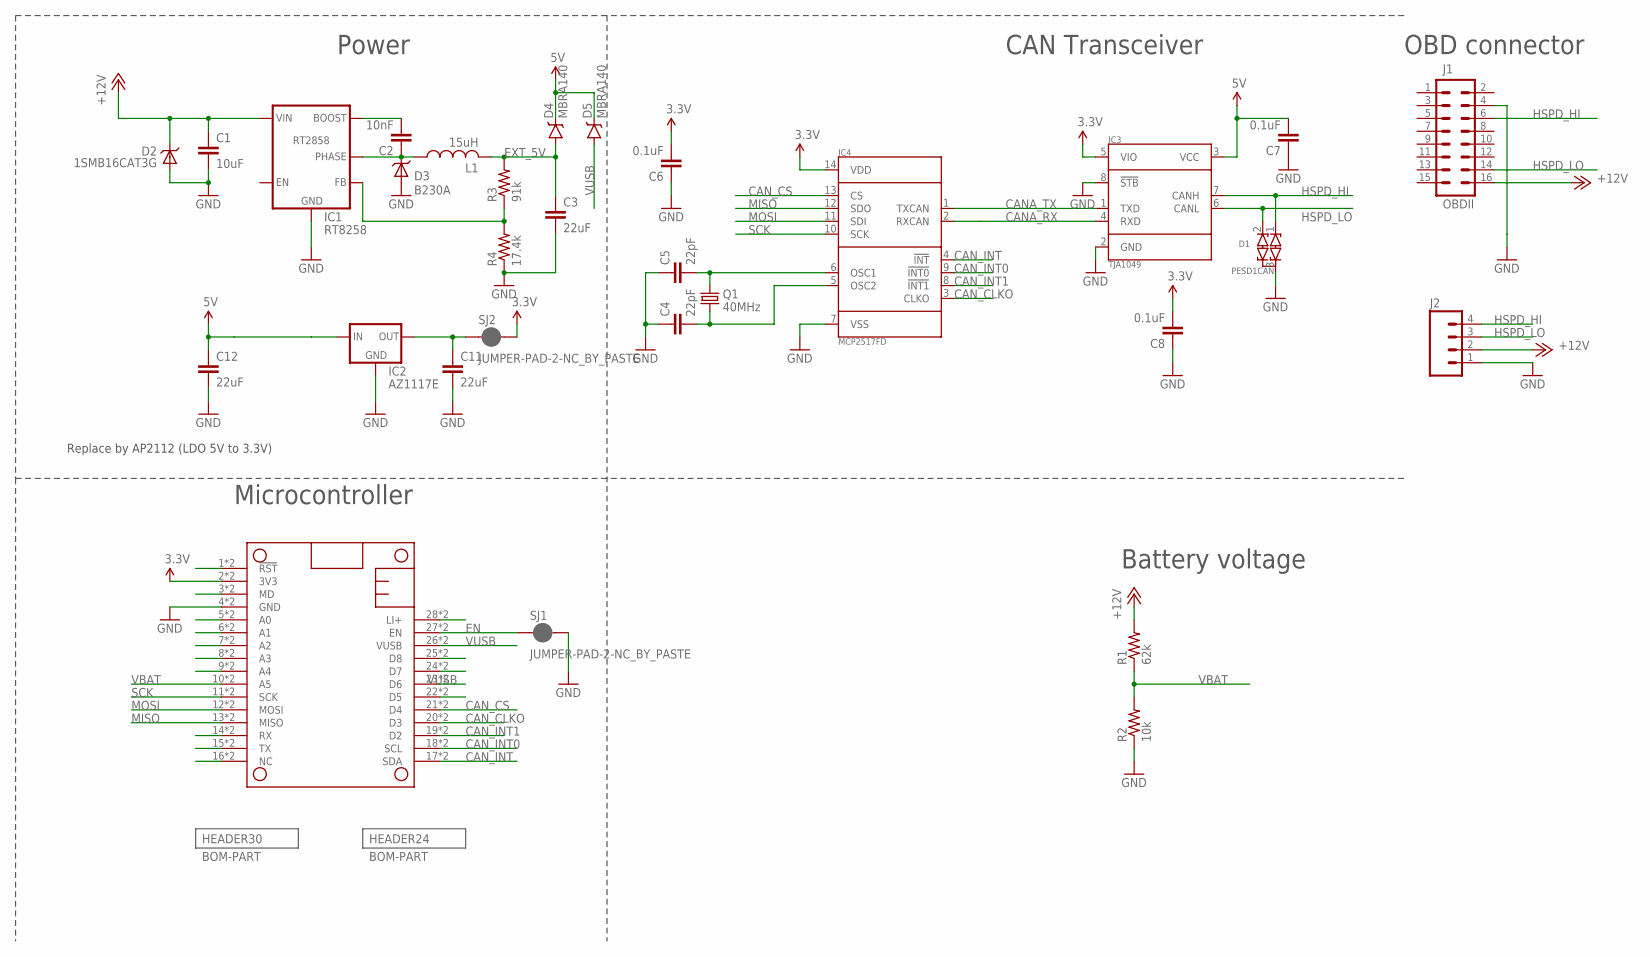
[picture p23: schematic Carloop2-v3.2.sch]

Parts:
C1: 10uF; C1206; PARTNO C3216X7R1E106K160AB
C2: 10nF; C0603; PARTNO CGA3E2X8R1H103K080AA
C3, C11, C12: 22uF; C1206; PARTNO CL31X226KAHN3NE
C4, C5: 22pF; C0603; PARTNO CC0603KRX7R9BB223
C6, C7, C8: 0.1uF; C0603; PARTNO CC0603JRX7R7BB104
D1: PESD1CAN; SOT23; PARTNO PESD1CAN-215
D2: 1SMB16CAT3G; SMB-DIODE; PARTNO 1SMB16CAT3G
D3: B230A; DO-214AA; PARTNO B230A-13-F
D4, D5: MBRA140; SMA-DIODE; PARTNO MBRA140T3G
IC1: RT8258; SOT-23-6; PARTNO RT8258GJ6
IC2: AZ1117E; SOT223; PARTNO AZ1117EH-3.3TRG1
IC3: TJA1049; SO8; PARTNO TJA1049T-118
IC4: MCP2517FD; SOIC-14; PARTNO MCP2517FD-H/SL
IC5: PARTICLE_MESH_SMTDUAL; FEATHERWING_SMT2
J1: OBDII; OBDII-COMTECH; PARTNO OBD-II
J2: M04SCREW; SCREWTERMINAL-3.5MM-4; PARTNO OSTTE040104
L1: 15uH; NR8040; PARTNO NR8040T150M
Q1: 40MHz; CRYSTAL-SMD-5X3; PARTNO ECS-400-12-30B-AGM-TR
R1: 62k; R0603; PARTNO ERA-3AEB623V
R2: 10k; R0603; PARTNO ERA-3AED103V
R3: 91k; R0603; PARTNO ERA-3ARB913V
R4: 17.4k; R0603; PARTNO ERJ-3EKF1742V
SJ1, SJ2: JUMPER-PAD-2-NC_BY_PASTE; PAD-JUMPER-2-NC_BY_PASTE_YES_SILK

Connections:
3.3V: C6.2, C8.2, IC3.5 (VIO), IC4.14 (VDD), IC5.2 (3V3), IC5.2' (3V3), SJ2.2
5V: C7.2, C12.1, D4.C, D5.C, IC2.3 (IN), IC3.3 (VCC)
+12V: C1.1, D2.C, IC1.5 (VIN), J1.16, J2.2, R1.2
BOOST\: C2.2, IC1.1 (BOOST)
CANA_RX: IC3.4 (RXD), IC4.2 (RXCAN)
CANA_TX: IC3.1 (TXD), IC4.1 (TXCAN)
CAN_CLKO: IC4.3 (CLKO), IC5.20 (D3), IC5.20' (D3)
CAN_CS: IC4.13 (CS), IC5.21 (D4), IC5.21' (D4)
CAN_INT: IC4.4 (!INT), IC5.17 (SDA), IC5.17' (SDA)
CAN_INT0: IC4.9 (!INT0), IC5.18 (SCL), IC5.18' (SCL)
CAN_INT1: IC4.8 (!INT1), IC5.19 (D2), IC5.19' (D2)
EN: IC5.27 (EN), IC5.27' (EN), SJ1.1
EXT_5V: C3.1, D4.A, L1.P$2 (2), R3.2
FB: IC1.3 (FB), R3.1, R4.2
GND: C1.2, C3.2, C4.1, C5.1, C6.1, C7.1, C8.1, C11.2, C12.2, D1.3 (COM), D2.A, D3.+ (A), IC1.2 (GND), IC2.1 (GND), IC2.4 (GND), IC3.2 (GND), IC3.8 (!STB), IC4.7 (VSS), IC5.4 (GND), IC5.4' (GND), J1.4, J2.1, R2.1, R4.1, SJ1.2
HSPD_HI: D1.1 (C1), IC3.7 (CANH), J1.6, J2.4
HSPD_LO: D1.2 (C2), IC3.6 (CANL), J1.14, J2.3
LI+: IC5.28 (LI+), IC5.28' (LI+)
MISO: IC4.12 (SDO), IC5.13 (MISO), IC5.13' (MISO)
MOSI: IC4.11 (SDI), IC5.12 (MOSI), IC5.12' (MOSI)
unnamed: C11.1, IC2.2 (OUT), SJ2.1
unnamed: C5.2, IC4.6 (OSC1), Q1.3 (2)
unnamed: IC5.1 (!RST), IC5.1' (!RST)
unnamed: IC5.3 (MD), IC5.3' (MD)
unnamed: IC5.5 (A0), IC5.5' (A0)
unnamed: IC5.6 (A1), IC5.6' (A1)
unnamed: IC5.7 (A2), IC5.7' (A2)
unnamed: IC5.8 (A3), IC5.8' (A3)
unnamed: IC5.9 (A4), IC5.9' (A4)
unnamed: IC5.25 (D8), IC5.25' (D8)
unnamed: IC5.24 (D7), IC5.24' (D7)
unnamed: IC5.23 (D6), IC5.23' (D6)
unnamed: IC5.22 (D5), IC5.22' (D5)
unnamed: IC5.14 (RX), IC5.14' (RX)
unnamed: IC5.15 (TX), IC5.15' (TX)
unnamed: IC5.16 (NC), IC5.16' (NC)
unnamed: C4.2, IC4.5 (OSC2), Q1.1
PHASE: C2.1, D3.- (C), IC1.6 (PHASE), L1.P$1 (1)
SCK: IC4.10 (SCK), IC5.11 (SCK), IC5.11' (SCK)
VBAT: IC5.10 (A5), IC5.10' (A5), R1.1, R2.2
VUSB: D5.A, IC5.26 (VUSB), IC5.26' (VUSB)

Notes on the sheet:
Power
Battery voltage
OBD connector
Microcontroller
CAN Transceiver
Replace by AP2112 (LDO 5V to 3.3V)

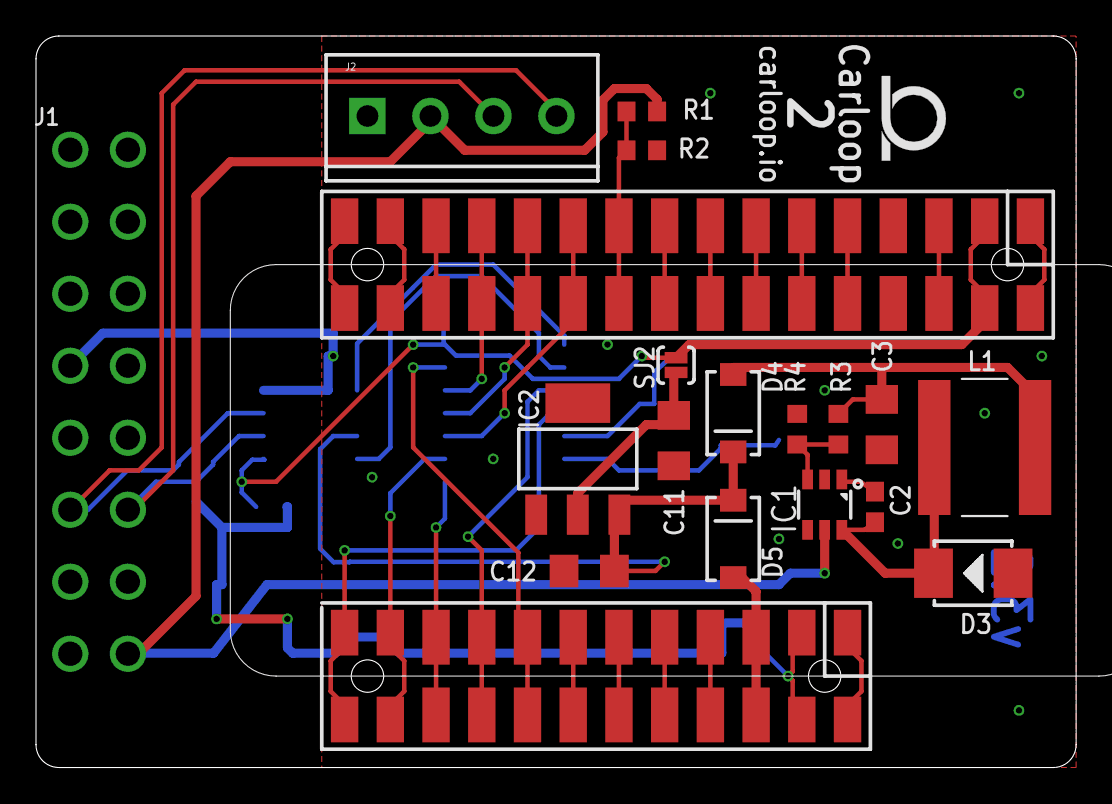
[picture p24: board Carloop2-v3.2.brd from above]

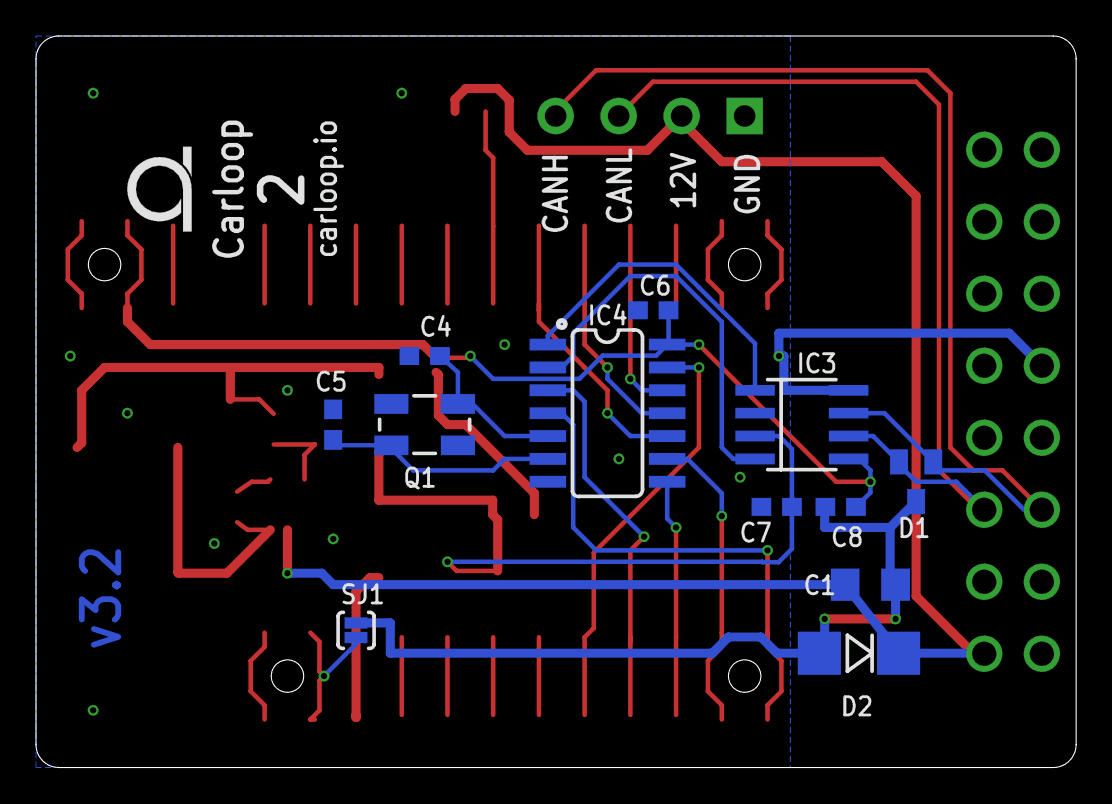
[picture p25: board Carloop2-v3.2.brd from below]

Board: 2 copper layers, 57.8 x 40.6 mm, 32 parts (13 on the bottom side), 41 nets.

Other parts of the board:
U$3, U$5: LOGOSMALL; CARLOOP-2

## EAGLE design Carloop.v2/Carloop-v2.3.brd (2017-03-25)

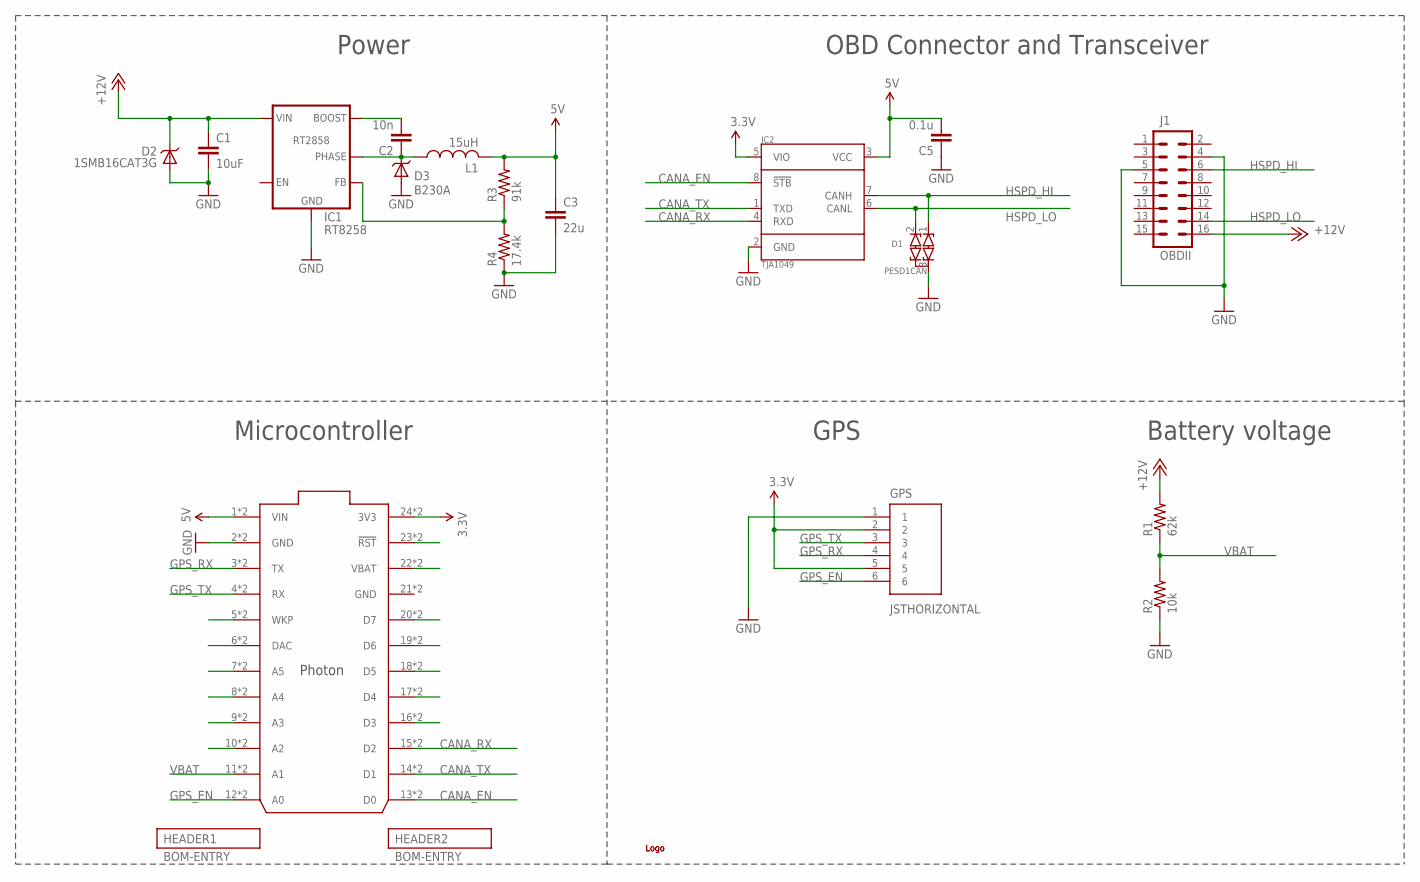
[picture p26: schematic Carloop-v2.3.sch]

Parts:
C1: 10uF; C1206; PARTNO GRM31CR61E106KA12L
C2: 10n; C0402; PARTNO C0402C103K5RACTU
C3: 22u; C1206; PARTNO GRM31CR61C226ME15L
C5: 0.1u; C0402; PARTNO GRM155R71C104KA88D
CORE: PHOTONWITH_EXTERNAL_HEADERS; PHOTON_STACKABLE_EXTERNAL; PARTNO *
D1: PESD1CAN; SOT23; PARTNO PESD1CAN-215
D2: 1SMB16CAT3G; SMB-DIODE; PARTNO 1SMB16CAT3G
D3: B230A; DO-214AA; PARTNO B230A-13-F
GPS: JSTHORIZONTAL; JST-6-SMD-HOR-1.0MM; PARTNO SM06B-SRSS-TB
IC1: RT8258; SOT-23-6; PARTNO RT8258GJ6
IC2: TJA1049; SO8; PARTNO TJA1049T-118
J1: OBDII; OBDII-STRAIGHT; PARTNO OBD-II
L1: 15uH; NR8040; PARTNO NR8040T150M
R1: 62k; R0402; PARTNO ERJ-2RKF6202X
R2: 10k; R0402; PARTNO ERJ-2RKF1002X
R3: 91k; R0402; PARTNO ERJ-2RKF9102X
R4: 17.4k; R0402; PARTNO ERJ-2RKF1742X
U$1, U$5: LOGOSMALL; CARLOOP-2

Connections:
3.3V: CORE.24 (3V3), CORE.@24 (3V3), GPS.2, GPS.5, IC2.5 (VIO)
5V: C3.1, C5.2, CORE.1 (VIN), CORE.@1 (VIN), IC2.3 (VCC), L1.P$2 (2), R3.2
+12V: C1.1, D2.C, IC1.5 (VIN), J1.16, R1.2
CANA_EN: CORE.13 (D0), CORE.@13 (D0), IC2.8 (!STB)
CANA_RX: CORE.15 (D2), CORE.@15 (D2), IC2.4 (RXD)
CANA_TX: CORE.14 (D1), CORE.@14 (D1), IC2.1 (TXD)
GND: C1.2, C3.2, C5.1, CORE.2 (GND), CORE.21 (GND), CORE.@2 (GND), CORE.@21 (GND), D1.3 (COM), D2.A, D3.+ (A), GPS.1, IC1.2 (GND), IC2.2 (GND), J1.4, J1.5, R2.1, R4.1
GPS_EN: CORE.12 (A0), CORE.@12 (A0), GPS.6
GPS_RX: CORE.3 (TX), CORE.@3 (TX), GPS.4
GPS_TX: CORE.4 (RX), CORE.@4 (RX), GPS.3
HSPD_HI: D1.1 (C1), IC2.7 (CANH), J1.6
HSPD_LO: D1.2 (C2), IC2.6 (CANL), J1.14
unnamed: C2.1, D3.- (C), IC1.6 (PHASE), L1.P$1 (1)
unnamed: C2.2, IC1.1 (BOOST)
unnamed: CORE.23 (!RST), CORE.@23 (!RST)
unnamed: CORE.22 (VBAT), CORE.@22 (VBAT)
unnamed: CORE.20 (D7), CORE.@20 (D7)
unnamed: CORE.19 (D6), CORE.@19 (D6)
unnamed: CORE.18 (D5), CORE.@18 (D5)
unnamed: CORE.17 (D4), CORE.@17 (D4)
unnamed: CORE.16 (D3), CORE.@16 (D3)
unnamed: IC1.3 (FB), R3.1, R4.2
unnamed: CORE.10 (A2), CORE.@10 (A2)
unnamed: CORE.9 (A3), CORE.@9 (A3)
unnamed: CORE.8 (A4), CORE.@8 (A4)
unnamed: CORE.7 (A5), CORE.@7 (A5)
unnamed: CORE.6 (DAC), CORE.@6 (DAC)
unnamed: CORE.5 (WKP), CORE.@5 (WKP)
VBAT: CORE.11 (A1), CORE.@11 (A1), R1.1, R2.2

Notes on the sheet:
OBD Connector and Transceiver
Power
Microcontroller
GPS
Battery voltage

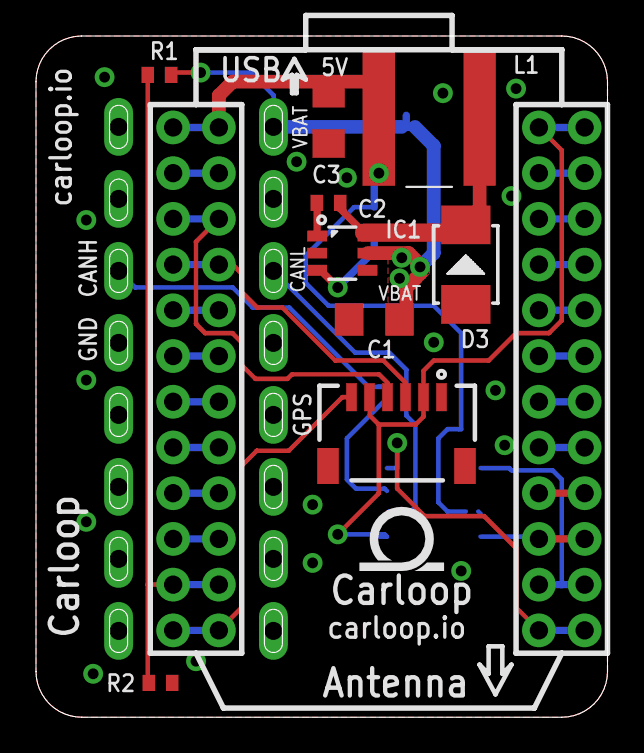
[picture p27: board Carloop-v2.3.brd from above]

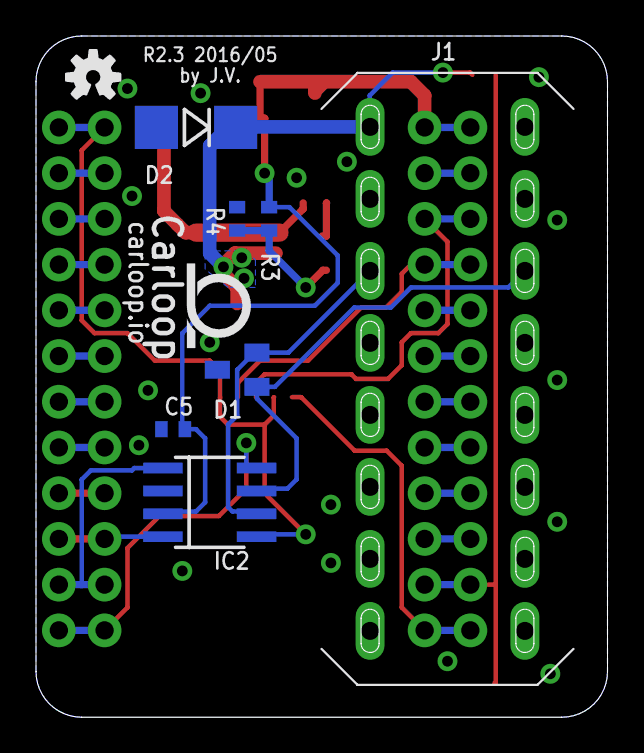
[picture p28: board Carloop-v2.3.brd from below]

Board: 2 copper layers, 31.8 x 37.8 mm, 21 parts (9 on the bottom side), 29 nets.

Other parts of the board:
F2: OSHW-LOGO-S
ZDRAW1: A4L-LOC

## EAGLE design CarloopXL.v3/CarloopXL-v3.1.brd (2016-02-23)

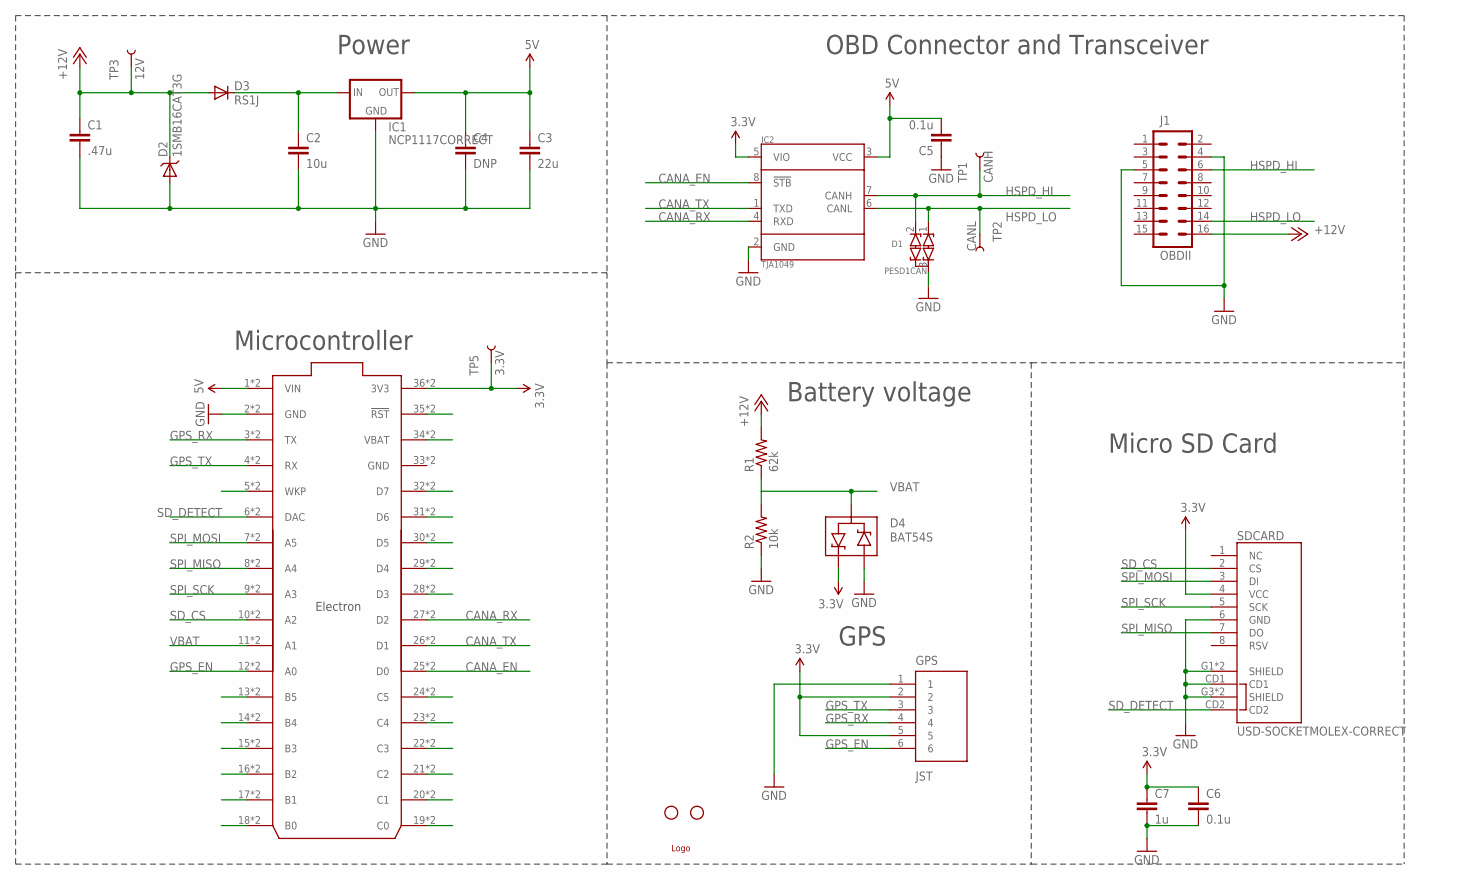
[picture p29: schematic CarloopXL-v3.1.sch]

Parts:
C1: .47u; C0805; PARTNO C0805C474K5RACTU
C2: 10u; C0805; PARTNO GRM21BR6YA106KE43L
C3: 22u; C0805; PARTNO GRM219R61A226MEA0D
C4: DNP; C0805; PARTNO GRM219R61A226MEA0D
C5, C6: 0.1u; C0805; PARTNO 08055C104KAT2A
C7: 1u; C0805; PARTNO CC0805KKX7R7BB105
D1: PESD1CAN; SOT23; PARTNO PESD1CAN-215
D2: 1SMB16CAT3G; SMB-DIODE; PARTNO 1SMB16CAT3G
D3: RS1J; SMA-DIODE; PARTNO RS1J-E3/5AT
D4: BAT54S; SOT23; PARTNO BAT54S-7-F
ELECTRON: ELECTRON_WITH_EXTERNAL_HEADERS; ELECTRON_EXTERNAL; PARTNO PPTC181LFBN-RC
GPS: JST; JST-6-SMD-VERT-1.0MM; PARTNO BM06B-SRSS-TB
IC1: NCP1117CORRECT; SOT223; PARTNO NCP1117LPST50T3G
IC2: TJA1049; SO8; PARTNO TJA1049T-118
J1: OBDII; OBDII-COMTECH; PARTNO OBD-II
R1: 62k; R0805; PARTNO ERJ-6ENF6202V
R2: 10k; R0805; PARTNO ERJ-6ENF1002V
SDCARD: USD-SOCKETMOLEX-CORRECT; MICRO-SD-MOLEX-CORRECT; PARTNO 1040310811
STANDOFF1, STANDOFF2: STAND-OFF
TP1: CANH; PAD.03X.03
TP2: CANL; PAD.03X.03
TP3: 12V; PAD.03X.03
TP5: 3.3V; PAD.03X.03
U$1: LOGO; CARLOOP

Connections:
3.3V: C6.1, C7.1, D4.2 (C1), ELECTRON.36 (3V3), ELECTRON.@36 (3V3), GPS.2, GPS.5, IC2.5 (VIO), SDCARD.4 (VCC), TP5.P$1
5V: C3.1, C4.1, C5.2, ELECTRON.1 (VIN), ELECTRON.@1 (VIN), IC1.2 (OUT), IC1.4 (OUT), IC2.3 (VCC)
+12V: C1.1, D2.C, D3.A, J1.16, R1.2, TP3.P$1
CANA_EN: ELECTRON.25 (D0), ELECTRON.@25 (D0), IC2.8 (!STB)
CANA_RX: ELECTRON.27 (D2), ELECTRON.@27 (D2), IC2.4 (RXD)
CANA_TX: ELECTRON.26 (D1), ELECTRON.@26 (D1), IC2.1 (TXD)
GND: C1.2, C2.2, C3.2, C4.2, C5.1, C6.2, C7.2, D1.3 (COM), D2.A, D4.1 (A2), ELECTRON.2 (GND), ELECTRON.33 (GND), ELECTRON.@2 (GND), ELECTRON.@33 (GND), GPS.1, IC1.1 (GND), IC2.2 (GND), J1.4, J1.5, R2.1, SDCARD.6 (GND), SDCARD.CD1, SDCARD.G1 (SHIELD), SDCARD.G2 (SHIELD), SDCARD.G3 (SHIELD), SDCARD.G4 (SHIELD)
GPS_EN: ELECTRON.12 (A0), ELECTRON.@12 (A0), GPS.6
GPS_RX: ELECTRON.3 (TX), ELECTRON.@3 (TX), GPS.4
GPS_TX: ELECTRON.4 (RX), ELECTRON.@4 (RX), GPS.3
HSPD_HI: D1.2 (C2), IC2.7 (CANH), J1.6, TP1.P$1
HSPD_LO: D1.1 (C1), IC2.6 (CANL), J1.14, TP2.P$1
unnamed: ELECTRON.13 (B5), ELECTRON.@13 (B5)
unnamed: ELECTRON.14 (B4), ELECTRON.@14 (B4)
unnamed: ELECTRON.35 (!RST), ELECTRON.@35 (!RST)
unnamed: ELECTRON.34 (VBAT), ELECTRON.@34 (VBAT)
unnamed: ELECTRON.32 (D7), ELECTRON.@32 (D7)
unnamed: ELECTRON.31 (D6), ELECTRON.@31 (D6)
unnamed: ELECTRON.30 (D5), ELECTRON.@30 (D5)
unnamed: ELECTRON.29 (D4), ELECTRON.@29 (D4)
unnamed: ELECTRON.28 (D3), ELECTRON.@28 (D3)
unnamed: ELECTRON.15 (B3), ELECTRON.@15 (B3)
unnamed: ELECTRON.16 (B2), ELECTRON.@16 (B2)
unnamed: ELECTRON.17 (B1), ELECTRON.@17 (B1)
unnamed: ELECTRON.18 (B0), ELECTRON.@18 (B0)
unnamed: ELECTRON.19 (C0), ELECTRON.@19 (C0)
unnamed: ELECTRON.20 (C1), ELECTRON.@20 (C1)
unnamed: ELECTRON.21 (C2), ELECTRON.@21 (C2)
unnamed: ELECTRON.5 (WKP), ELECTRON.@5 (WKP)
unnamed: ELECTRON.23 (C4), ELECTRON.@23 (C4)
unnamed: ELECTRON.24 (C5), ELECTRON.@24 (C5)
unnamed: ELECTRON.22 (C3), ELECTRON.@22 (C3)
unnamed: C2.1, D3.C, IC1.3 (IN)
SD_CS: ELECTRON.10 (A2), ELECTRON.@10 (A2), SDCARD.2 (CS)
SD_DETECT: ELECTRON.6 (DAC), ELECTRON.@6 (DAC), SDCARD.CD2
SPI_MISO: ELECTRON.8 (A4), ELECTRON.@8 (A4), SDCARD.7 (DO)
SPI_MOSI: ELECTRON.7 (A5), ELECTRON.@7 (A5), SDCARD.3 (DI)
SPI_SCK: ELECTRON.9 (A3), ELECTRON.@9 (A3), SDCARD.5 (SCK)
VBAT: D4.3 (COM), ELECTRON.11 (A1), ELECTRON.@11 (A1), R1.1, R2.2

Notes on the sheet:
OBD Connector and Transceiver
Power
Microcontroller
GPS
Micro SD Card
Battery voltage

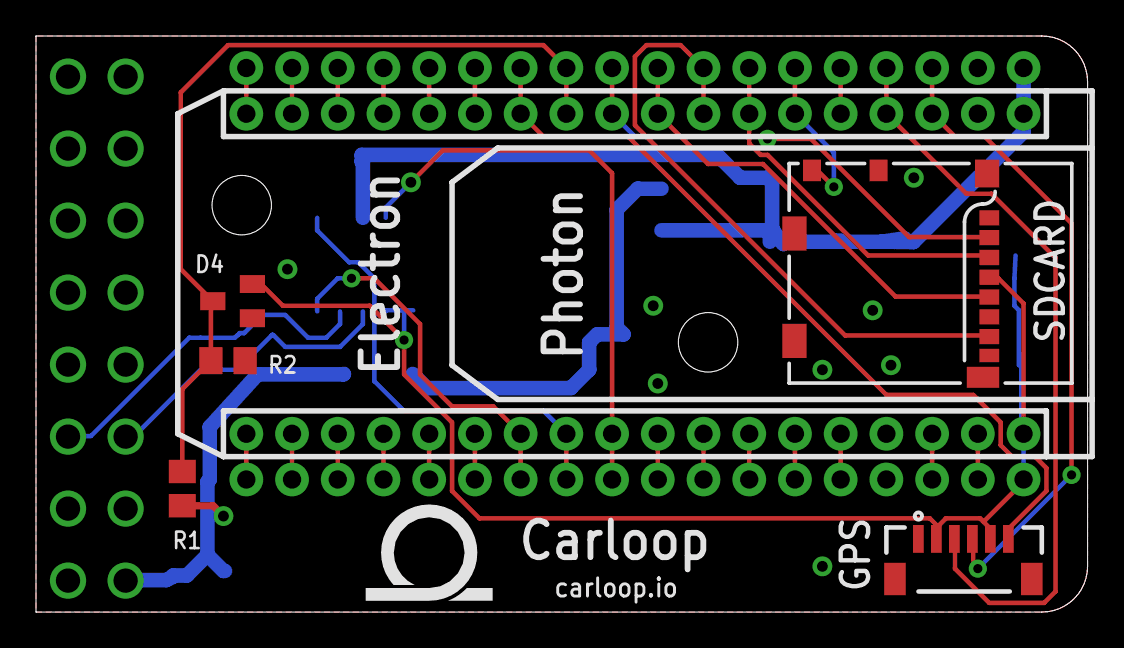
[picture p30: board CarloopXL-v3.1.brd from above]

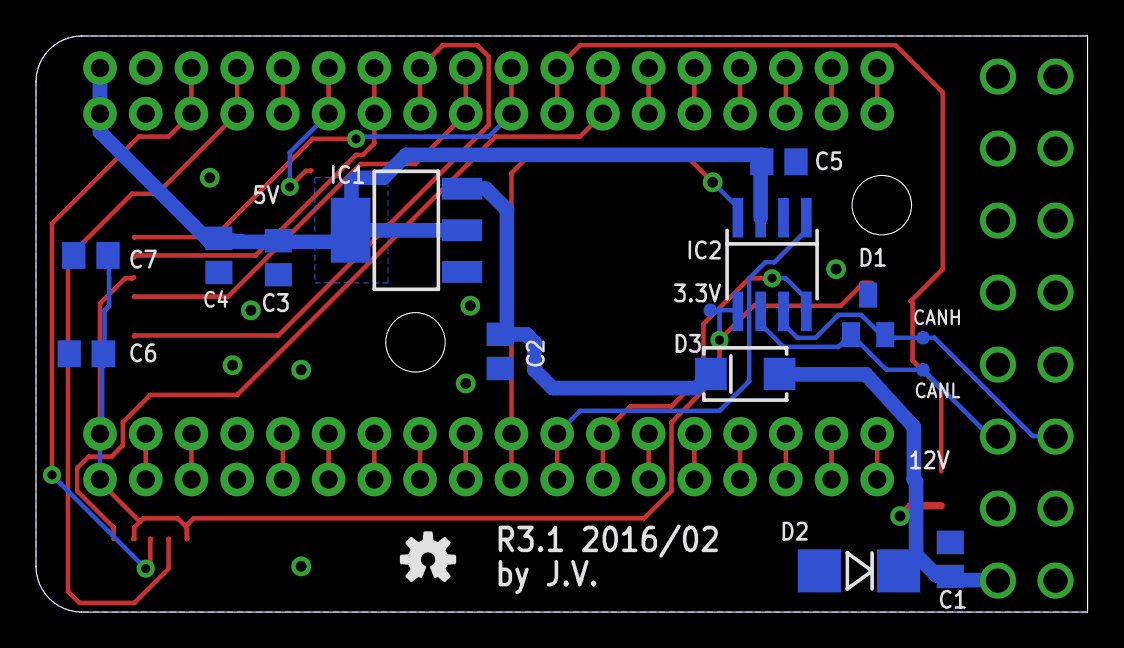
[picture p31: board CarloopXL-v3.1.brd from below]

Board: 2 copper layers, 58.4 x 32.0 mm, 28 parts (17 on the bottom side), 39 nets.

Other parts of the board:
F2: OSHW-LOGO-S
ZDRAW1: A4L-LOC

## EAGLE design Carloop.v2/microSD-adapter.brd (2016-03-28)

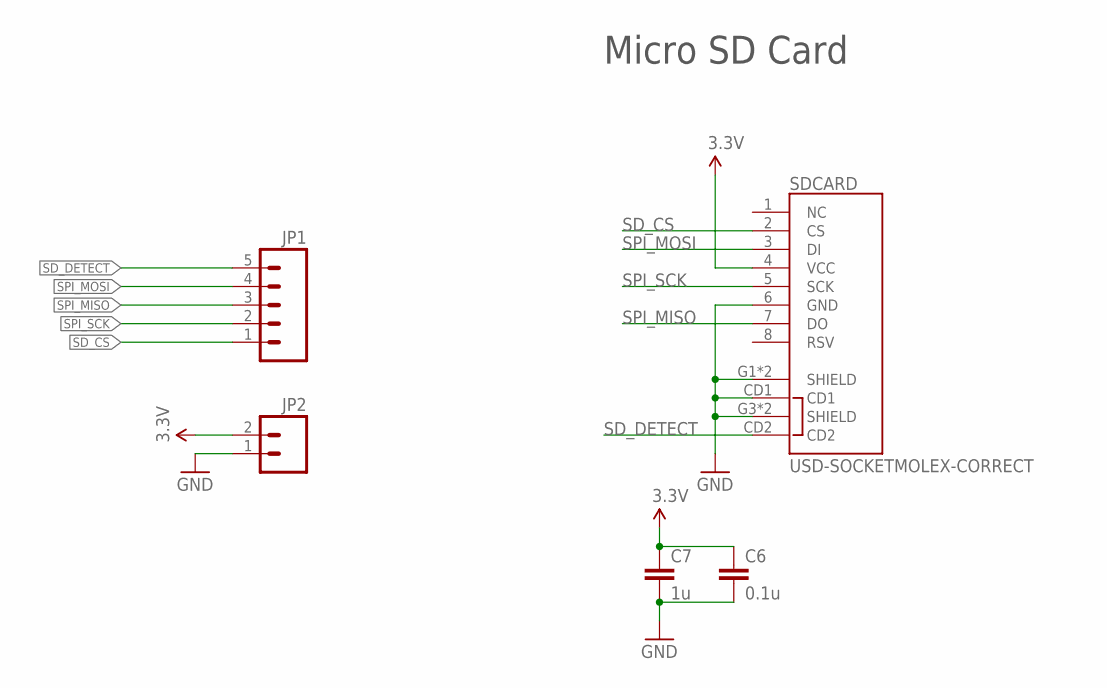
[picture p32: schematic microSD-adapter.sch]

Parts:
C6: 0.1u; C0805; PARTNO 08055C104KAT2A
C7: 1u; C0805; PARTNO CC0805KKX7R7BB105
JP1: M05PTH; 1X05
JP2: M02PTH; 1X02
SDCARD: USD-SOCKETMOLEX-CORRECT; MICRO-SD-MOLEX-CORRECT; PARTNO 1040310811

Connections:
3.3V: C6.1, C7.1, JP2.2, SDCARD.4 (VCC)
GND: C6.2, C7.2, JP2.1, SDCARD.6 (GND), SDCARD.CD1, SDCARD.G1 (SHIELD), SDCARD.G2 (SHIELD), SDCARD.G3 (SHIELD), SDCARD.G4 (SHIELD)
SD_CS: JP1.1, SDCARD.2 (CS)
SD_DETECT: JP1.5, SDCARD.CD2
SPI_MISO: JP1.3, SDCARD.7 (DO)
SPI_MOSI: JP1.4, SDCARD.3 (DI)
SPI_SCK: JP1.2, SDCARD.5 (SCK)

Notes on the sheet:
Micro SD Card

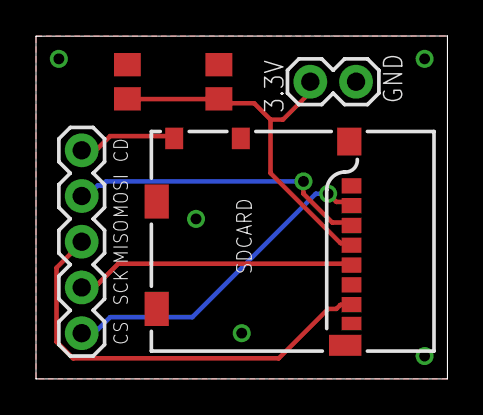
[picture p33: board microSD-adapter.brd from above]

Board: 2 copper layers, 22.9 x 19.1 mm, 5 parts (0 on the bottom side), 7 nets.

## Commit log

2016-01-12 Add revision 1.1 design files and images
    [particle-can-v1.1.brd, particle-can-v1.1.sch, particle-can-v1.1_BOM.csv]
2016-01-13 fixes typo to make BOM 'beautiful and searchable'
    [particle-can-v1.1_BOM.csv]
2016-01-25 Revision 2: smaller transceiver, simpler power, GPS
    [particle-can-v2.0.brd, particle-can-v2.0.sch]
2016-01-27 Version 2 of the PCB has optimized components and GPS
    [particle-can-v1.1.brd, particle-can-v1.1.sch, particle-can-v1.1_BOM.csv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]
2016-01-28 Revision 3 has the PCB extending outward and SD card
    [particle-can-v3.0.brd, particle-can-v3.0.sch, particle-can-v3.0_BOM.csv]
2016-02-01 Revision 3 grows outward (different form factor)
    [particle-can-v3.0.brd, particle-can-v3.0.sch, particle-can-v3.0_BOM.csv]
2016-02-15 Update Readme to show V3 schematics
    [particle-can-v2.0.brd, particle-can-v2.0.sch, particle-can-v3.0.brd]
2016-02-23 Revision 2.1 and 3.1
    [particle-can-v2.1.brd, particle-can-v2.1.sch, particle-can-v2.1_BOM.csv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]
2016-02-24 Add schematic for R2.1
2016-03-28 Carloop PCB revision 2.2
    - Flip the GPS connector landing pattern
    - Add 2nd header to BOM
    [microSD-adapter.brd, microSD-adapter.sch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]
2016-05-27 Carloop R2.3 with switching power supply
    [particle-can-v2.3.brd, particle-can-v2.3.sch]
2016-05-31 Add BOM and Gerber files for Rev 2.3
    [particle-can-v2.3.GBL, particle-can-v2.3.GBO, particle-can-v2.3.GBP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]
2016-09-21 updated PCB picture
2016-10-10 Rename schematic files to Carloop
    [Carloop-v1.1.brd, Carloop-v1.1.sch, Carloop-v1.1_BOM.csv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]
2017-02-10 Add files via upload
    Schematic with K-Line Transceiver added, based on Carloop.v3.1 design.
    Board Layout is not completed.
    [CarloopRetro-v0.1.brd, CarloopRetro-v0.1.sch]
2017-02-10 Rename CarloopRetro-v0.1.brd to CarloopRetro-v0/CarloopRetro-v0.1.brd
    Placing file in correct folder structure
    [CarloopRetro-v0.1.brd]
2017-02-10 Rename CarloopRetro-v0/CarloopRetro-v0.1.brd to CarloopRetro.v0/CarloopRetro-v0.1.brd
    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
    [CarloopRetro-v0.1.brd]
2017-02-10 Rename CarloopRetro-v0.1.sch to CarloopRetro.v0/CarloopRetro-v0.1.sch
    Place file in correct folder structure
    [CarloopRetro-v0.1.sch]
2017-02-20 Update variants
    [CarloopXL-v3.0.brd, CarloopXL-v3.0.sch, CarloopXL-v3.0_BOM.csv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]
2017-03-16 v2.3 schematics
2017-03-25 Make layers visible by default
    [Carloop-v2.3.brd]
2017-04-20 Add draft of GPS shield
    [GPS_Shield.v1.brd, GPS_Shield.v1.sch]
2017-04-26 Add GPS_EN
    [GPS_Shield.v1.brd, GPS_Shield.v1.sch]
2017-05-08 Tweaks for silkscreen
    [GPS_Shield.v1.brd, GPS_Shield.v1.sch]
2018-08-29 Draft of Carloop2
    [Carloop2-v3.1.brd, Carloop2-v3.1.sch]
2018-08-29 First prototype of Carloop 2
    [Carloop2-v3.1.brd, Carloop2-v3.1.sch, Carloop2-v3.1_BOM.csv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]
2018-11-13 Fix PCB bugs
    [Carloop2-v3.2.brd, Carloop2-v3.2.sch]
2018-11-13 Add prototype of Carloop Stick
    [CarloopStick-v1.1.brd, CarloopStick-v1.1.sch]
2019-07-07 Update GPS shield schematic
    [GPS_Shield.v1.brd, GPS_Shield.v1.sch]

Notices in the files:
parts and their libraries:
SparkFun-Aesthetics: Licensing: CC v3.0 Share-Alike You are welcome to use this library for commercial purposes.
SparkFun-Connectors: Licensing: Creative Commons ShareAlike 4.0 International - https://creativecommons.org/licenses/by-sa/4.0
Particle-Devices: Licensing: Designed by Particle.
